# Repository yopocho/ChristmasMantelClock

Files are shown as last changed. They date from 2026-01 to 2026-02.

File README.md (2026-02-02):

<p align="left">
  <a href="https://github.com/zephyrproject-rtos/zephyr">
    
  </a>
  <a href="https://www.altium.com/altium-designer">
    
  </a>
  <a href="">
    
  </a>
</p>

# Christmas Mantel Clock

Hardware and firmware for a my 2025 christmas present to friends and family. This repository describes the device I designed, which is built around an STM32 microcontroller running Zephyr RTOS with LVGL/EEZ Studio UI.

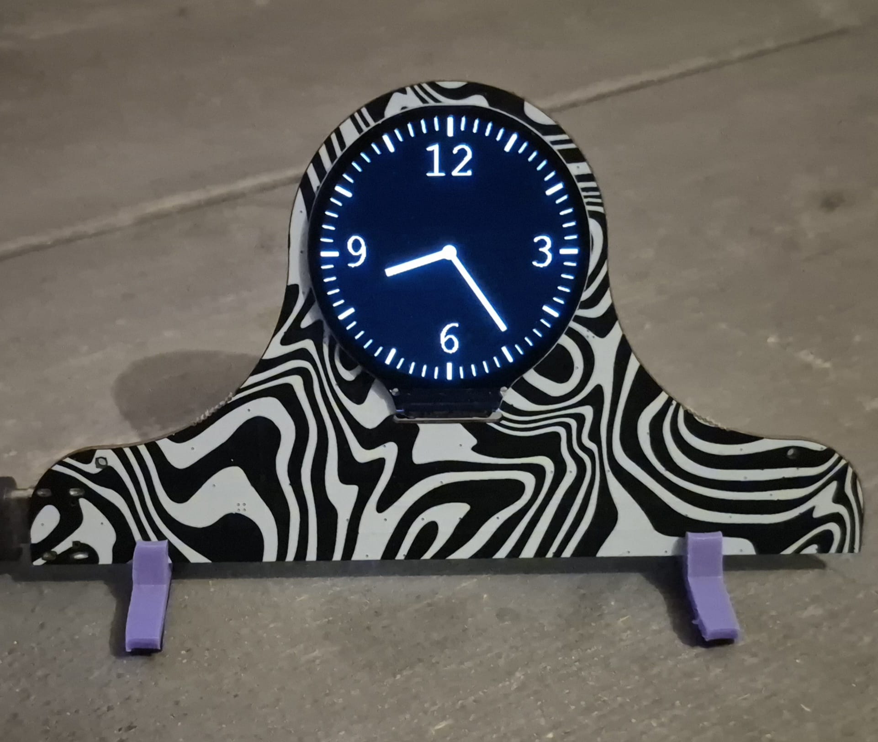
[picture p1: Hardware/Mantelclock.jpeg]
Image of the finished mantel clock


This repository is intended as a reference for the design, including electronics, firmware, and build configuration.

## Features

- Custom PCB and hardware design
- GC9A01 240x240 1.28" round LCD
- Zephyr RTOS board definition based on the PCB
- STM32F405-based firmware
- Zephyr RTOS configuration
- Windows-based build scripts

Designed as a standalone mantel clock, nice for on the mantel!

## Getting Started

### Prerequisites

- ARM GCC toolchain
- CMake 3.20 or newer
- Zephyr SDK and dependencies
- West Metatool
- Windows build environment (CMD or PowerShell)

### Build

From the repository root:

```bat
build.bat
```

To perform a clean (pristine) build:

```bat
build_pristine.bat
```

## Configuration

- `mantelclock_defconfig`
  Default configuration associated with the mantel clock board, enabling required drivers and functionality for bare-bones implementation
- `prj.conf`  
  Implementation-specific configuration

## Flashing and Debugging

1. Connect a supported debugger (ST-Link, J-Link, etc.). 
3. Flash the generated image to the target device (DFU or SWD).
4. Use a SWO-capable debugger for live SWO-trace logging and debugging

## Hardware

Hardware design files, including schematics and PCB layouts, are located under the `Hardware/` directory.
To replicate, simply use the supplied gerbers, -BOM and -CPL files and order the board (assembled) at JLCPCB.

Hardware designed using Altium Designer

## License

Apache License 2.0

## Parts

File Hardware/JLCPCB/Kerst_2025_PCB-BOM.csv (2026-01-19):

Comment | Description | Designator | Footprint | LibRef | Quantity | LCSC Part #
MY-2032-28 | Battery clip Nickel Phosphor Bronze CR2032 SMD Button And Strip Battery Connector ROHS | BT301 | MY-2032-28 | CMP-00029-00004-3 | 1
100n | Capacitor SMD 0402 | C201, C302, C304, C305, C306, C307, C308, C405 | CAP_0402 | CMP-001-00084-3 | 8 | C1525
2u2 | Capacitor SMD 0402 | C202, C203, C403, C404, C501, C502, C503 | CAP_0402 | CMP-001-00084-3 | 7 | C12530
1u | Capacitor SMD 0402 | C204, C205 | CAP_0402 | CMP-001-00084-3 | 2 | C52923
10u | Capacitor SMD 0603 | C301, C303, C504 | CAP_0603 | CMP-001-00085-2, CMP-001-00085-5 | 3 | C19702
14p 50V | Capacitor SMD 0402 | C401, C402 | CAP_0402 | CMP-001-00084-3 | 2 | C1548
15p 50V | Capacitor SMD 0402 | C406, C407 | CAP_0402 | CMP-001-00084-3 | 2 | C1548
USBLC6-2SC6 | Low-Capacitance ESD Protection USB | D201 | SOT-23-6 | CMP-004-00035-1 | 1 | C7519
LED_0603_RED | LED 0603 RED SMD | D401 | LED_0603_RED | CMP-004-00040-1 | 1 | C2286
D_BI_TVS_SOD_323 | Bidirectional TVS Diode SMD SOD-323 | D402, D403, D404 | SOD-323 | CMP-004-00068-3 | 3 | C20615802
MINISMDC020F-2 | PTC RESET FUSE 30V 200MA 1812 | F201 | FP-MINISMDC020F-2-MFG | CMP-08606-000054-1 | 1 | C5418
120R | Chip Ferrite Bead, 0603, 120O @ 100MHz, 0.05O, 25%, 2A BLM18PG121SN1D | FB201 | FP-BLM18-0_15-t0_8-IPC_A | CMP-0686-00557-7 | 1 | C14709
TYPE-C-31-M-12 | USB Type-C Connector JLCPCB C165948 | J201 | CONN12_C-31-M-12_HRO | CMP-002-00157-2 | 1 | C165948
HL2305 | P-CHANNEL 20-V (D-S) MOSFET SI2301CDS-T1-GE3 (PLACEHOLDER FOR ACTUAL PART HL2305 LCSC C28646261) | Q301 | TO-236_VIS | CMP-013-00034-4 | 1 | C28646261
AO3400A | MOSFET N-CH 30V 5.7A SOT23 | Q501 | FP-SOT23-MFG | CMP-83955-000006-1 | 1 | C20917
5k1 | Resistor SMD 0402 | R201, R202 | RES_0402 | CMP-009-00178-2 | 2 | C25905
0R | Resistor SMD 0402 | R401, R407, R504 | RES_0402 | CMP-009-00178-2 | 3 | C17168
10k | Resistor SMD 0402 | R402, R403, R404, R406, R408, R501, R503 | RES_0402 | CMP-009-00178-2 | 7 | C25744
1k | Resistor SMD 0402 | R405 | RES_0402 | CMP-009-00178-2 | 1 | C11702
51R | Resistor SMD 0805 | R502 | RES_0805 | CMP-009-00180-3 | 1 | C17738
TS-1088-AR02016 | Without Bracket 4mm 12V 3mm Round Button SPST 50mA SMD,4x3mm Tactile Switches RoHS | SW401, SW402, SW403 | SW_TS-1088_XNP | CMP-011-00038-2 | 3 | C720477
XC6206P332MR-G | 1uA 200mA 3.3V 6V Fixed Over Current Protection Positive SOT-23-3L Voltage Regulators - Linear, Low Drop Out (LDO) Regulators ROHS | U201 | SOT-23_TOR | CMP-019-00049-5 | 1 | C5446
STM32F405RGT6 | MCU 32-bit STM32F ARM Cortex M4F RISC 1024KB Flash 2.5V/3.3V 64-Pin LQFP Tray | U401 | STM-LQFP64_M | CMP-031-00038-1 | 1 | C15742
LDK220M30R | 200 mA low quiescent current and low noise LDO | U501 | SOT23-5L_1P75X3P05X0P95_STM | CMP-019-00050-3 | 1 | C5267990
25MHz 12pF | Crystal SMD 25MHz 10PPM 12pF 3225 X322525MOB4SI YXC JLCPCB C9006 | X401 | XTAL_3225 | CMP-003-00033-1 | 1 | C9006
32.768kHz 12.5pF | 32.768kHz Crystal Oscillator (JLCPCB C32346) | X402 | XTAL_FC-135_EPS | CMP-003-00034-4 | 1 | C32346

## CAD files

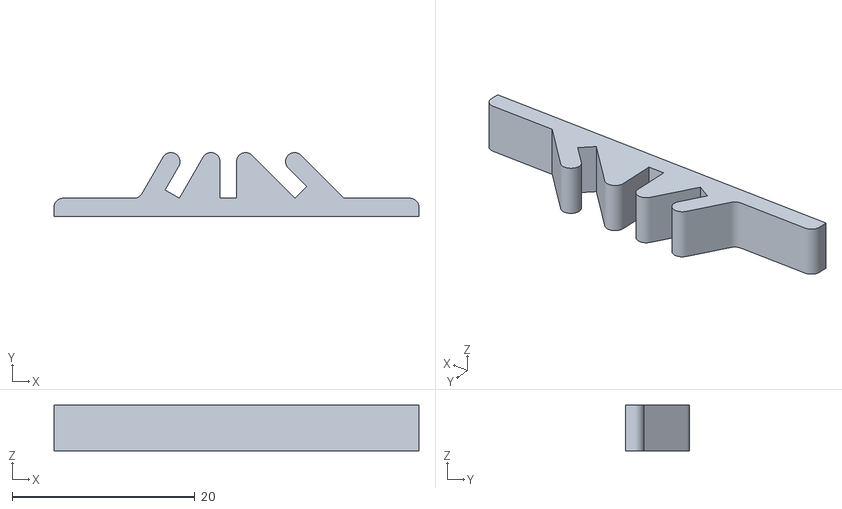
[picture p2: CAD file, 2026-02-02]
Hardware/Mantel_Clock_Stand.stl
40.0 x 7.00 x 5.00

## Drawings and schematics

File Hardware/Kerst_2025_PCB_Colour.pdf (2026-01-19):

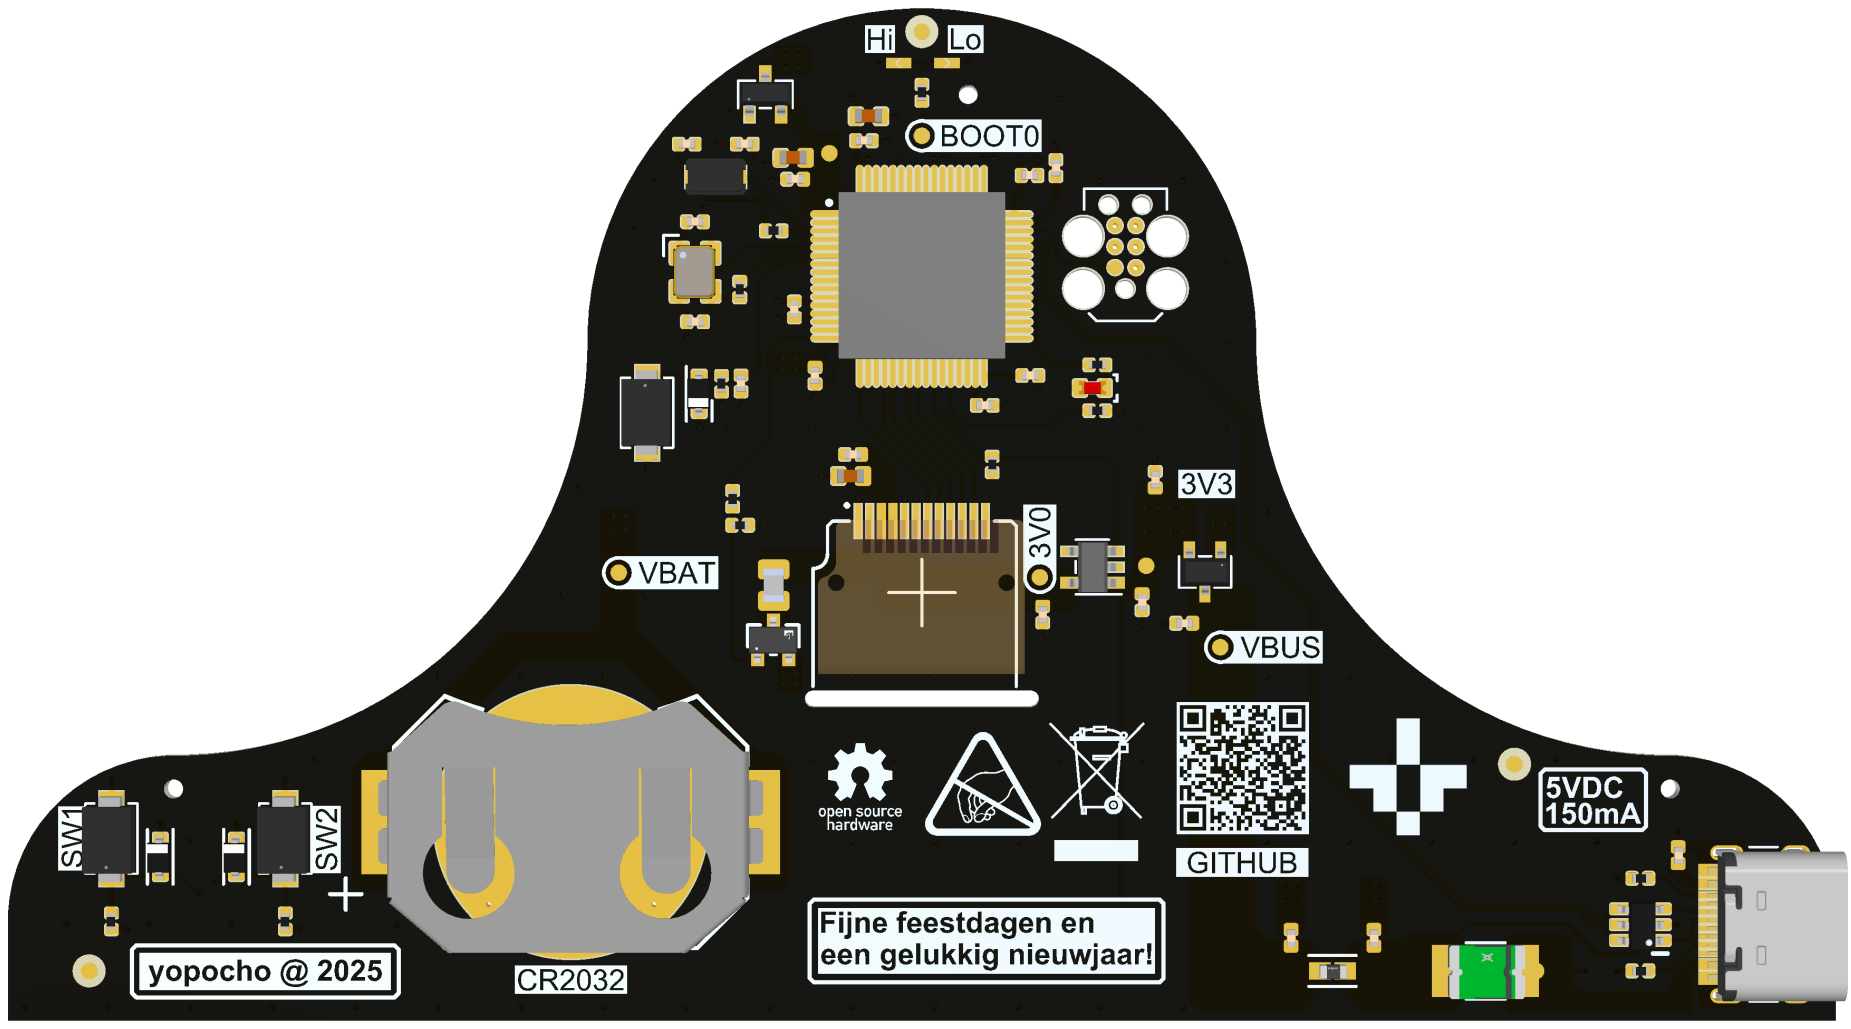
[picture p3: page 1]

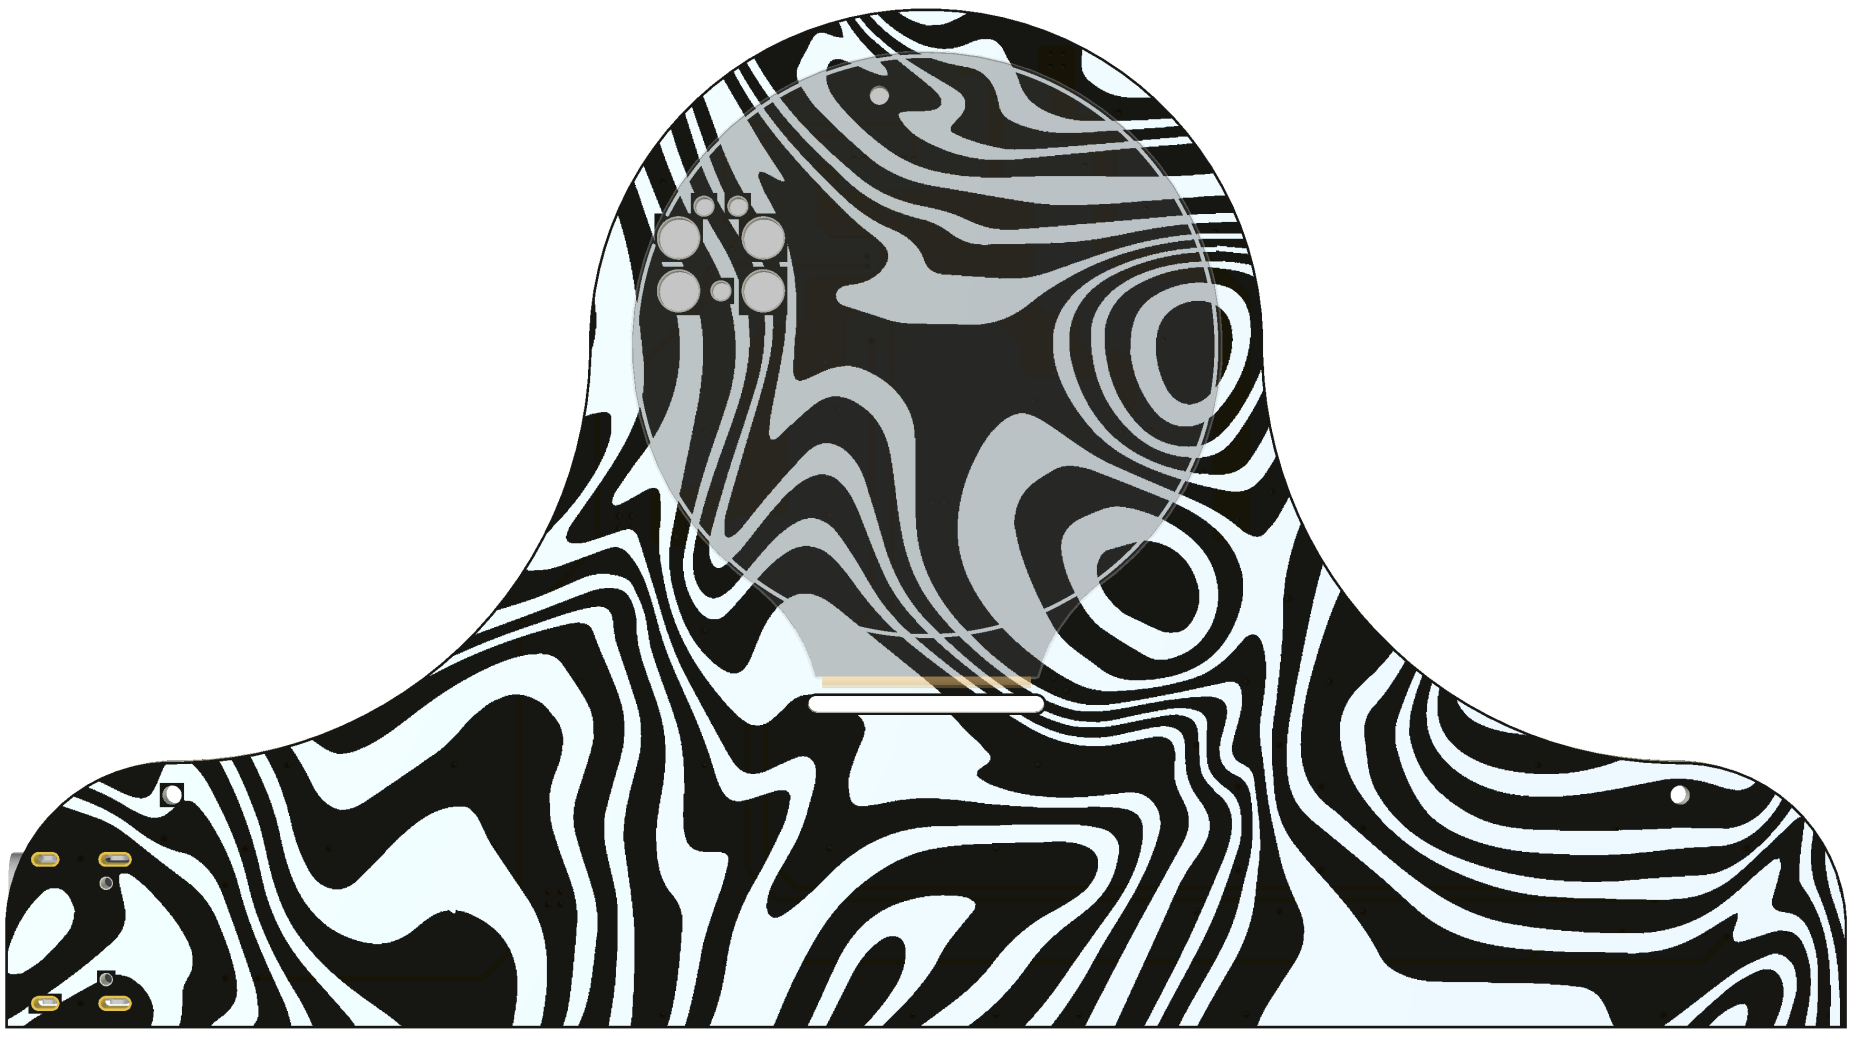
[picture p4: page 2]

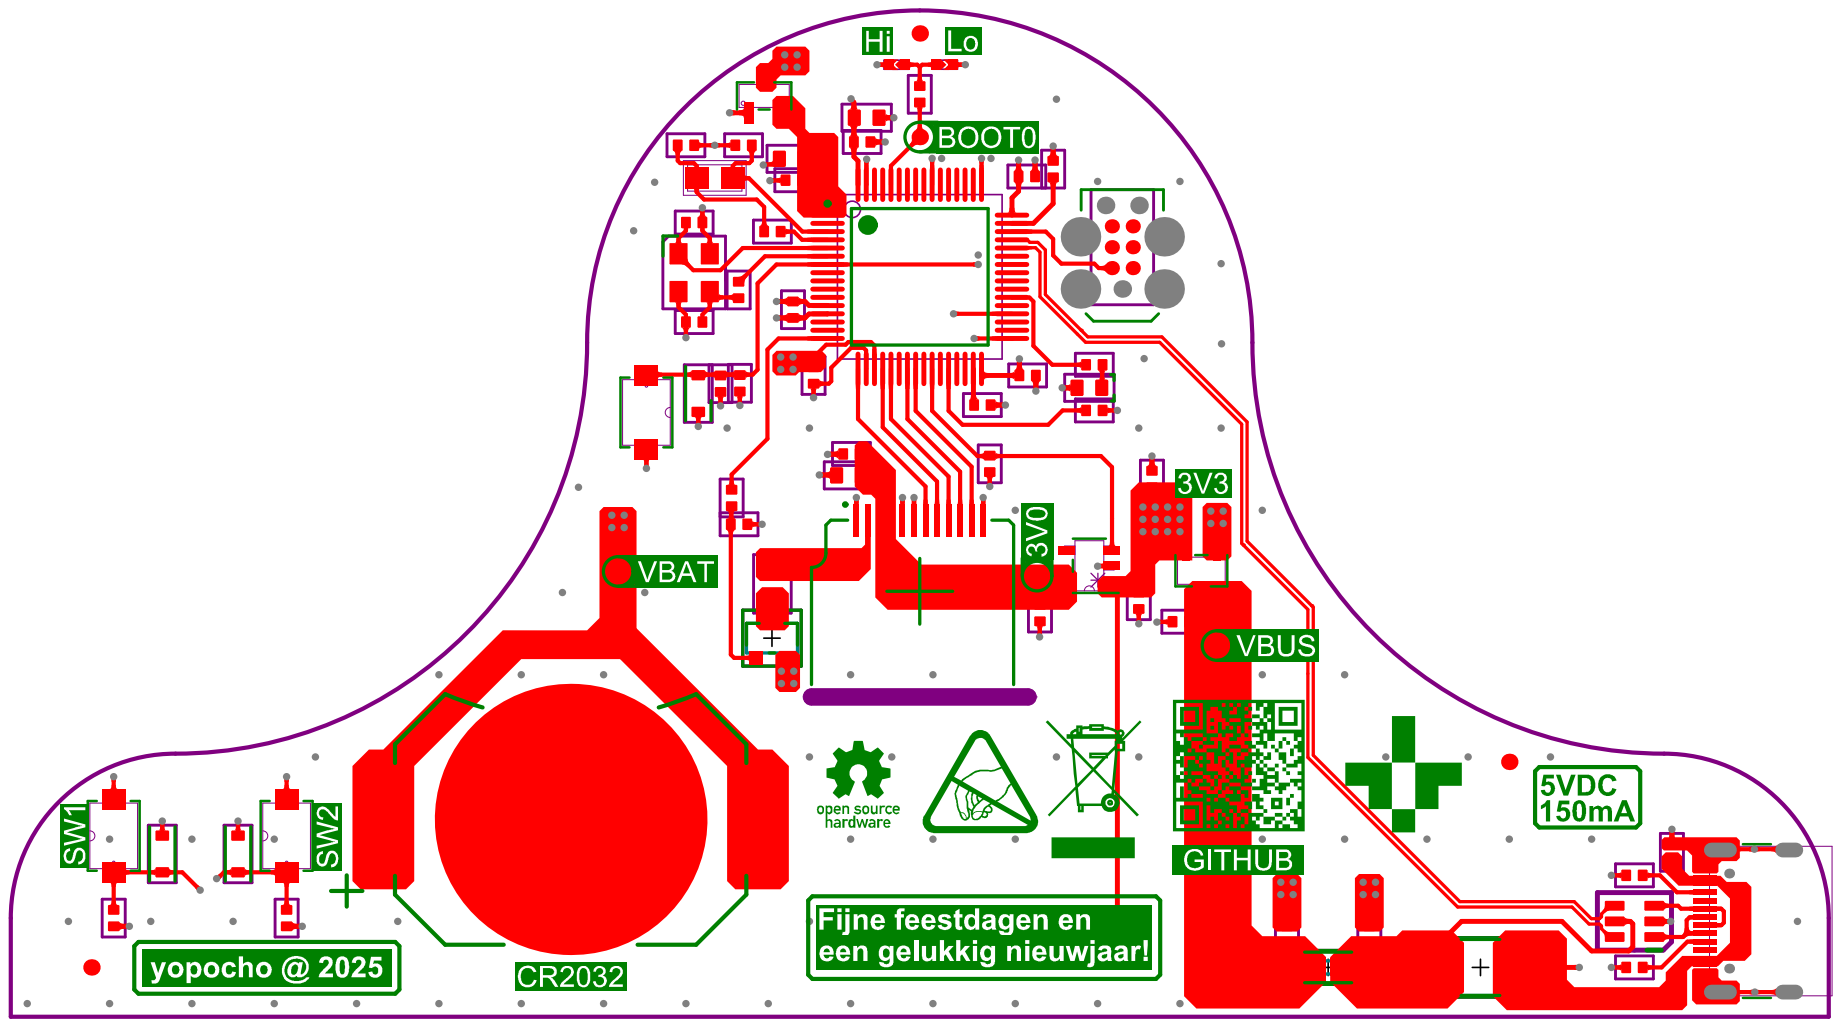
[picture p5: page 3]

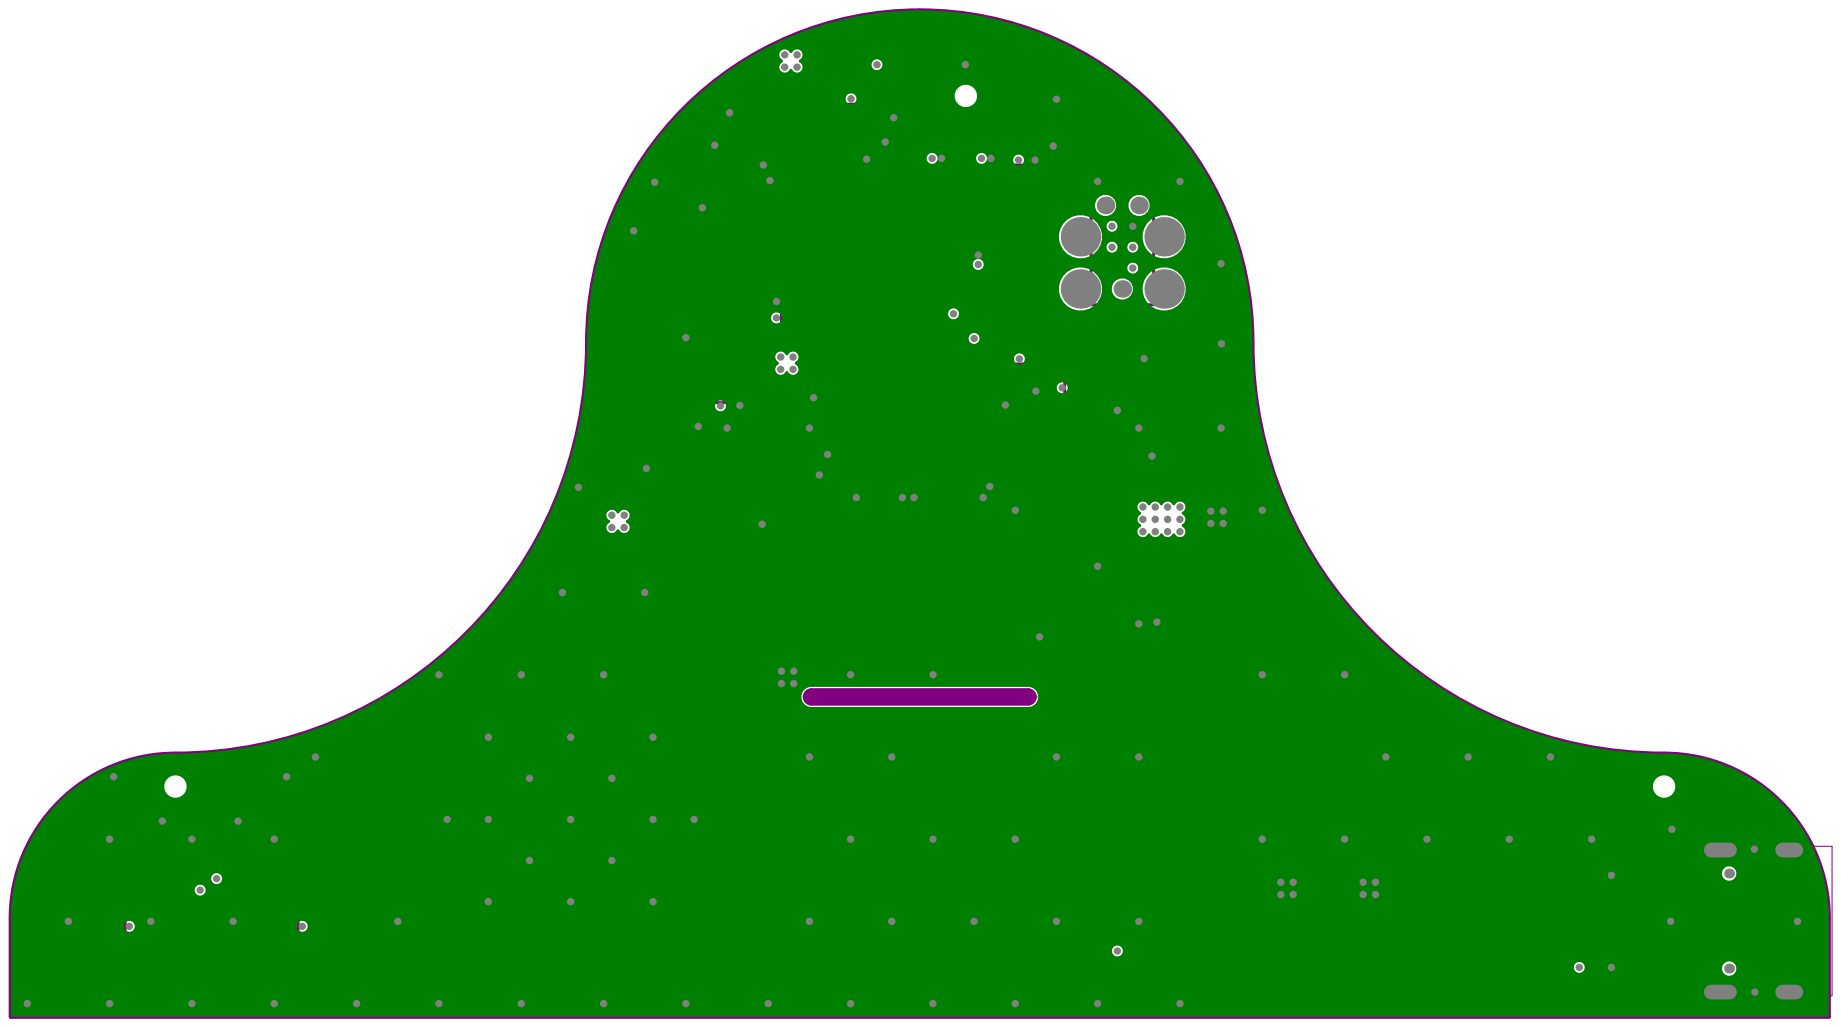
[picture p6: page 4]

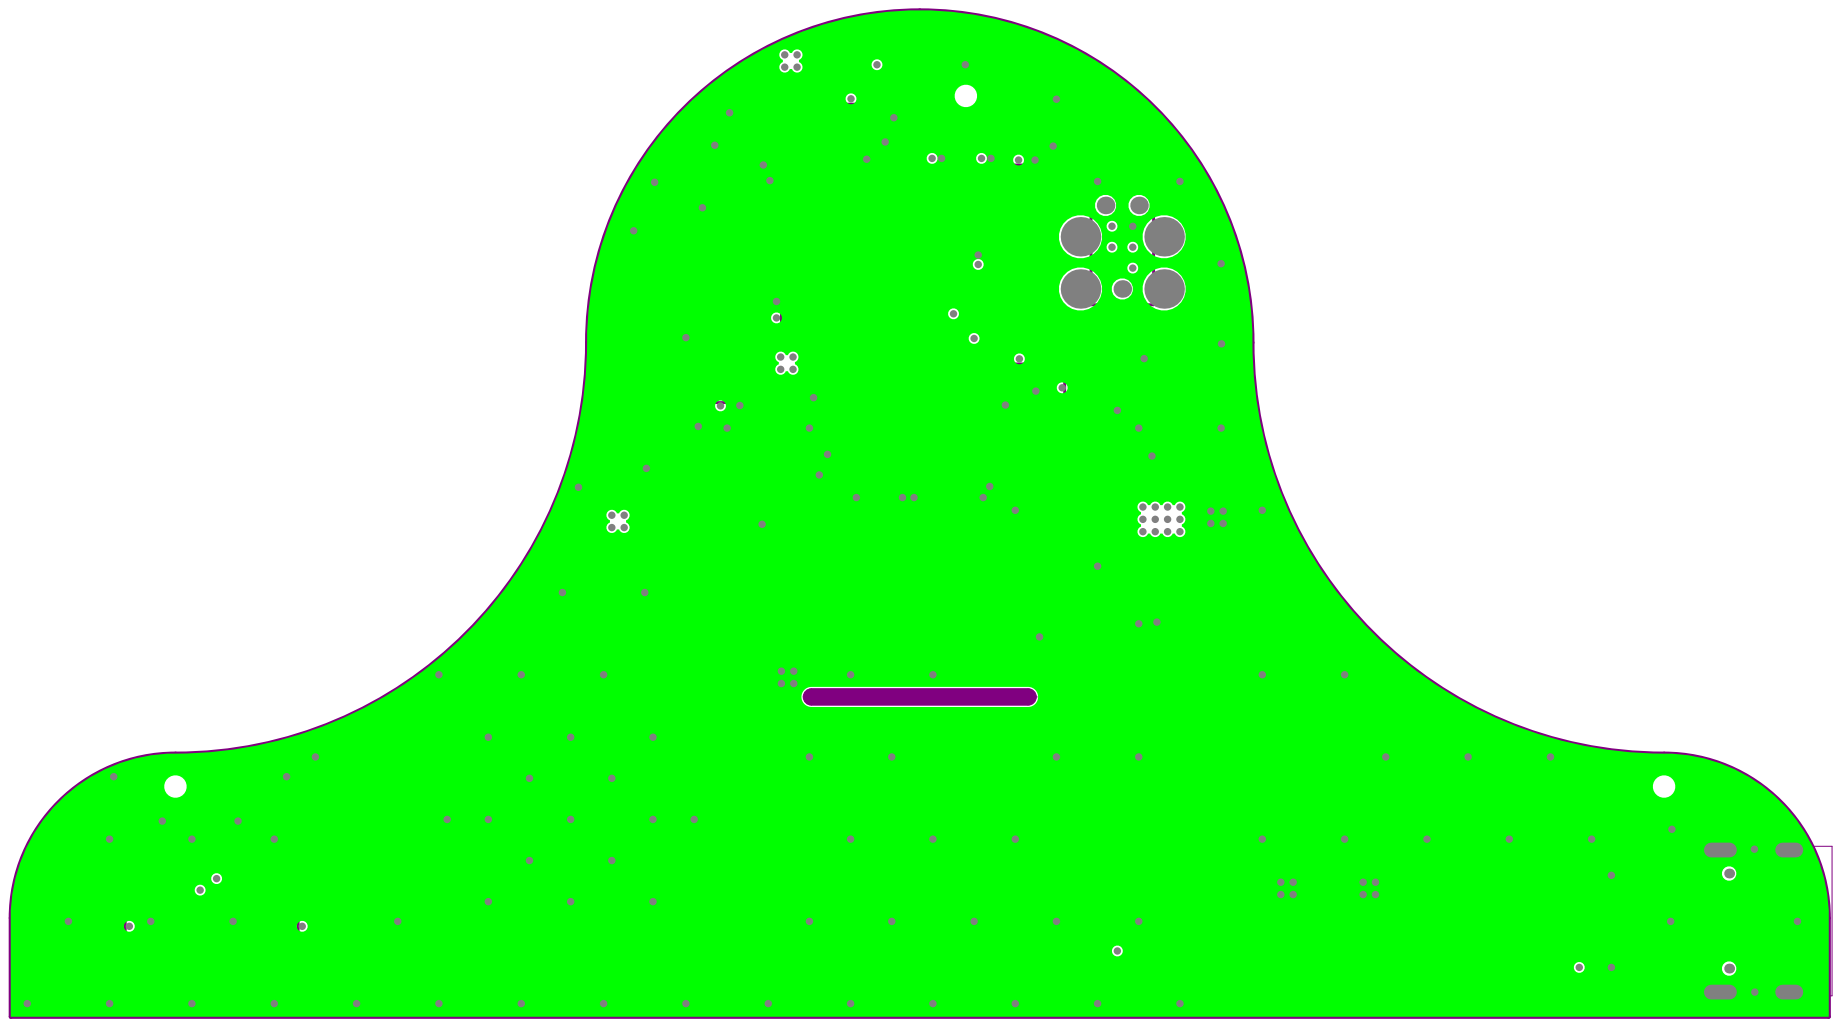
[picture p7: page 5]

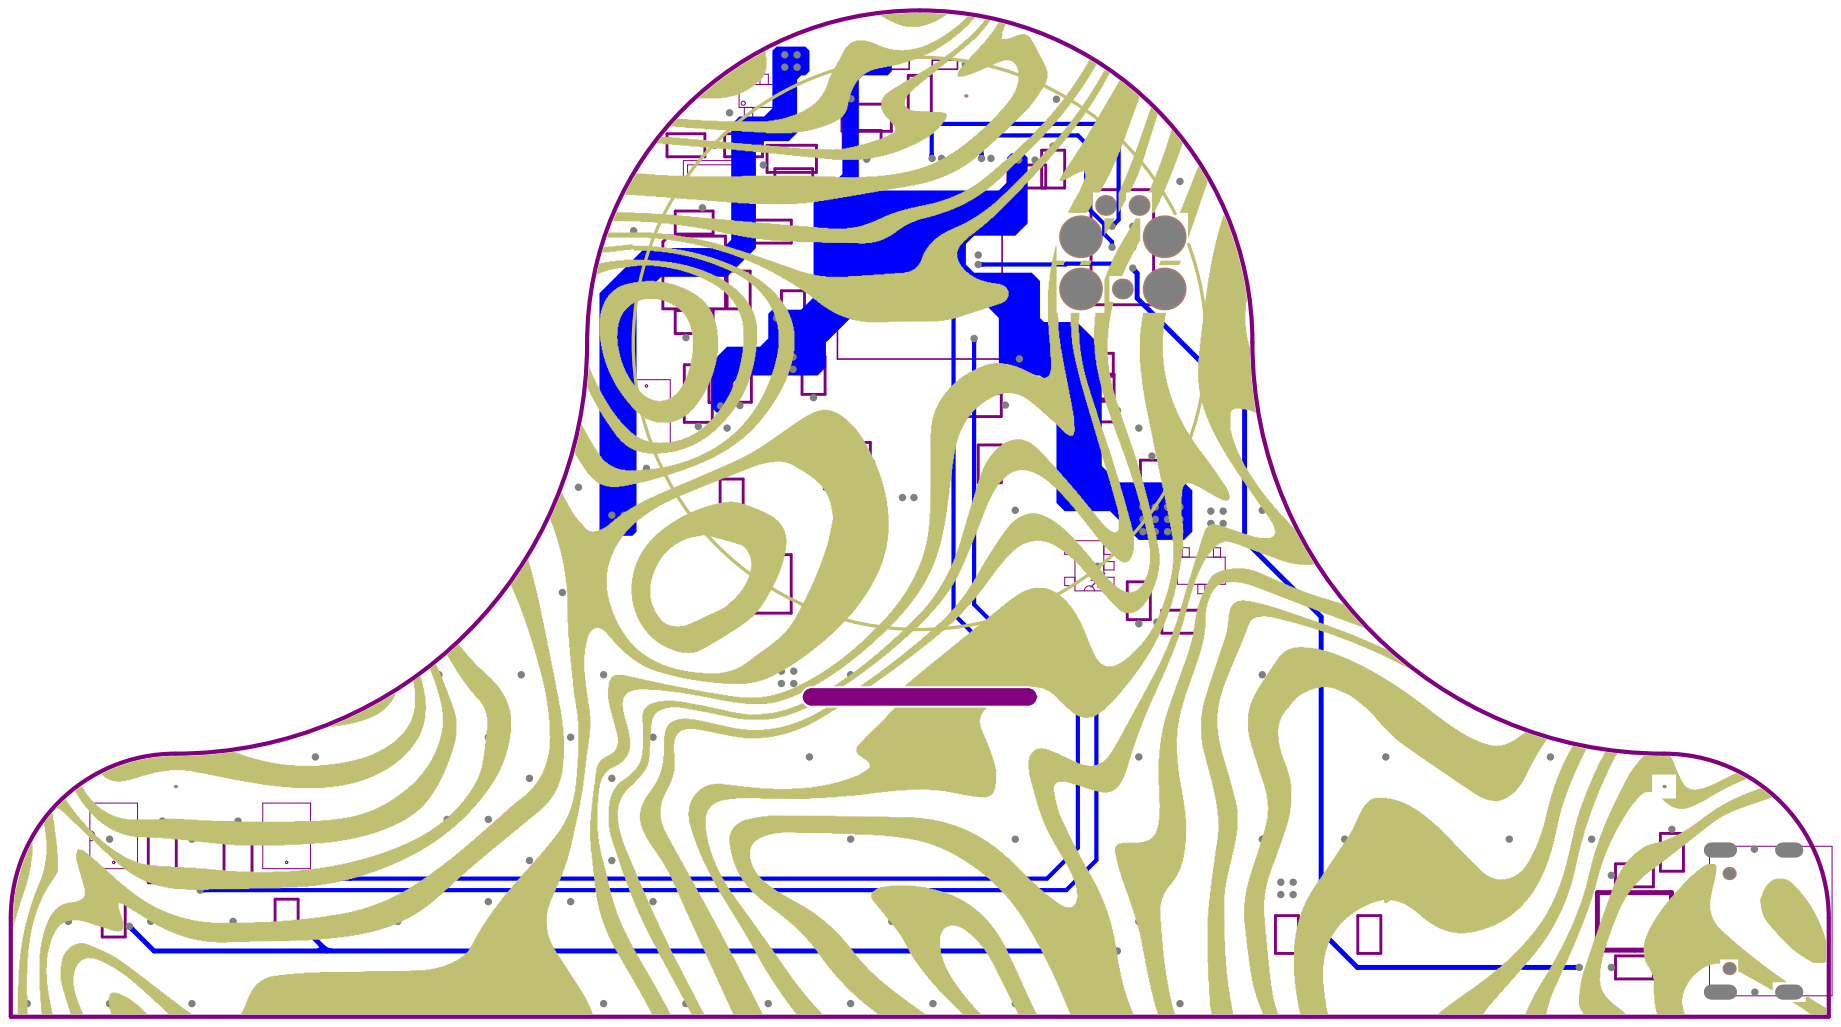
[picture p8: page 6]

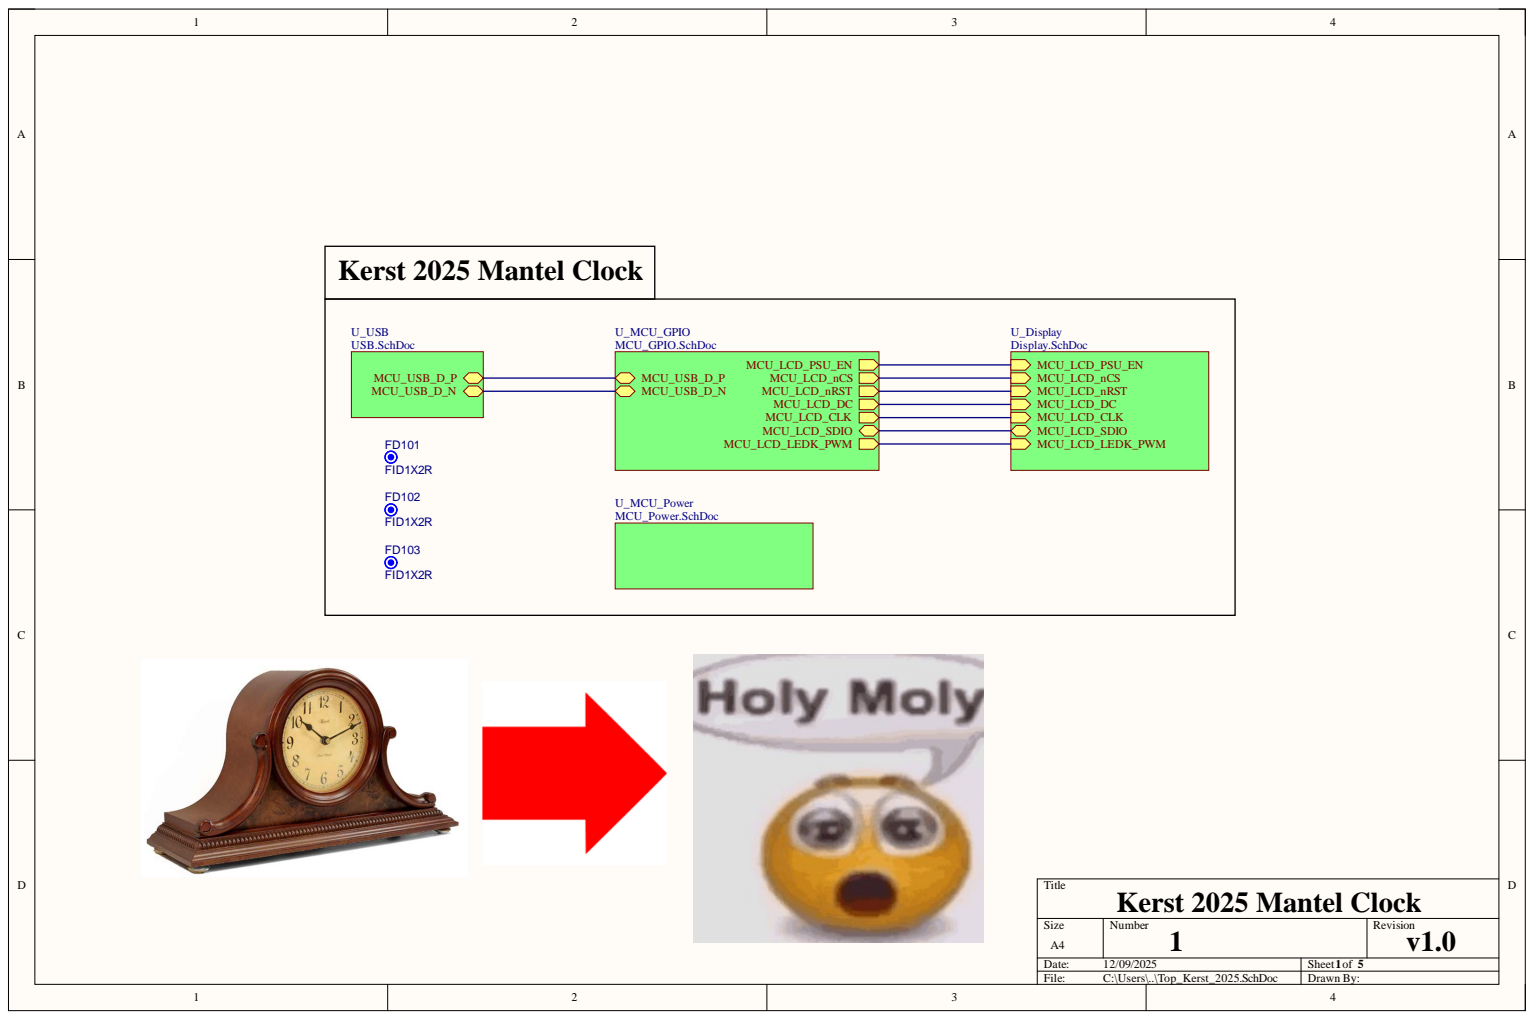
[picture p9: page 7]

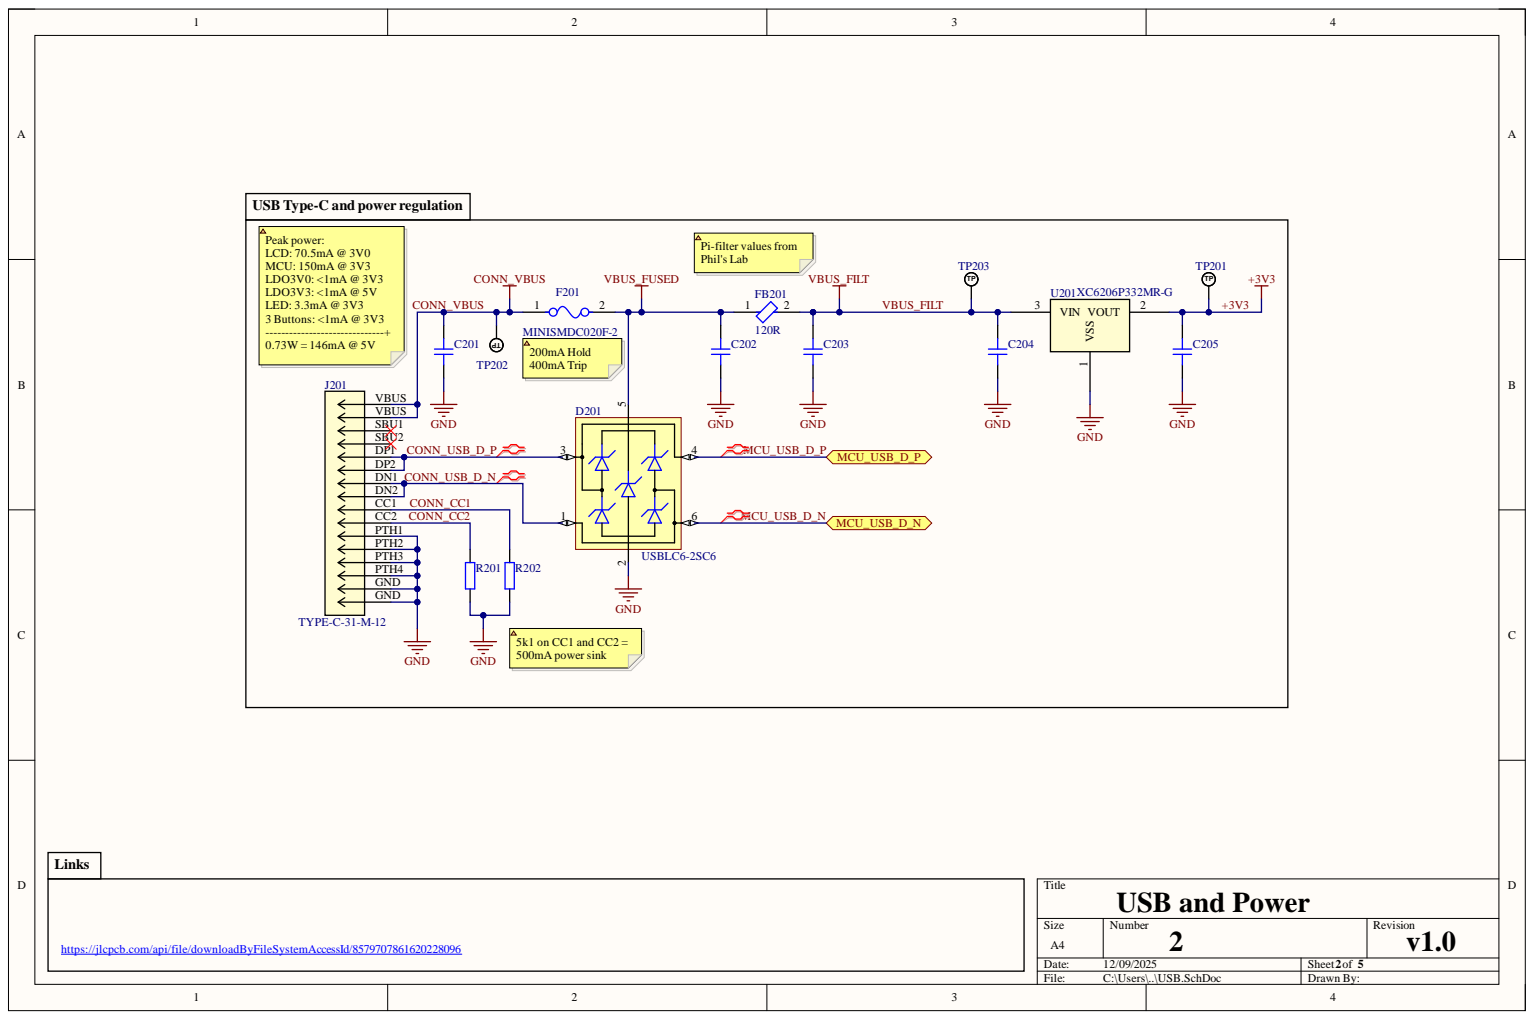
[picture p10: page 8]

USB Type-C and power regulation

Pi-filter values from
Phil's Lab

https://jlcpcb.com/api/file/downloadByFileSystemAccessId/8579707861620228096

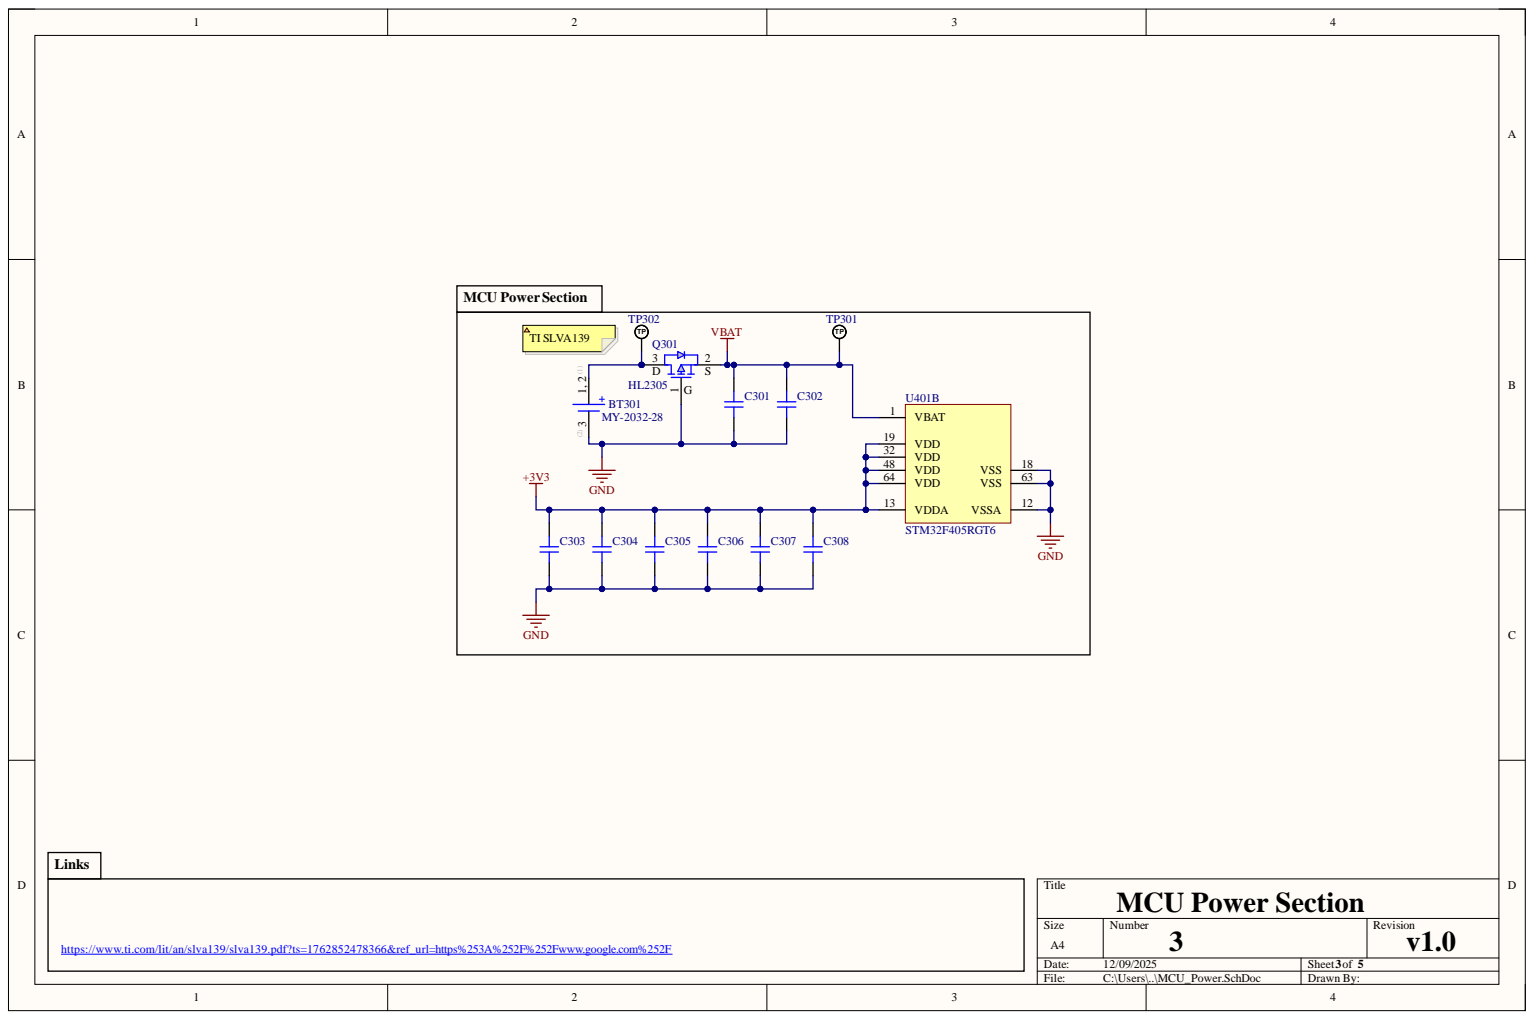
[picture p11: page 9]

https://www.ti.com/lit/an/slva139/slva139.pdf?ts=1762852478366&ref_url=https%253A%252F%252Fwww.google.com%252F

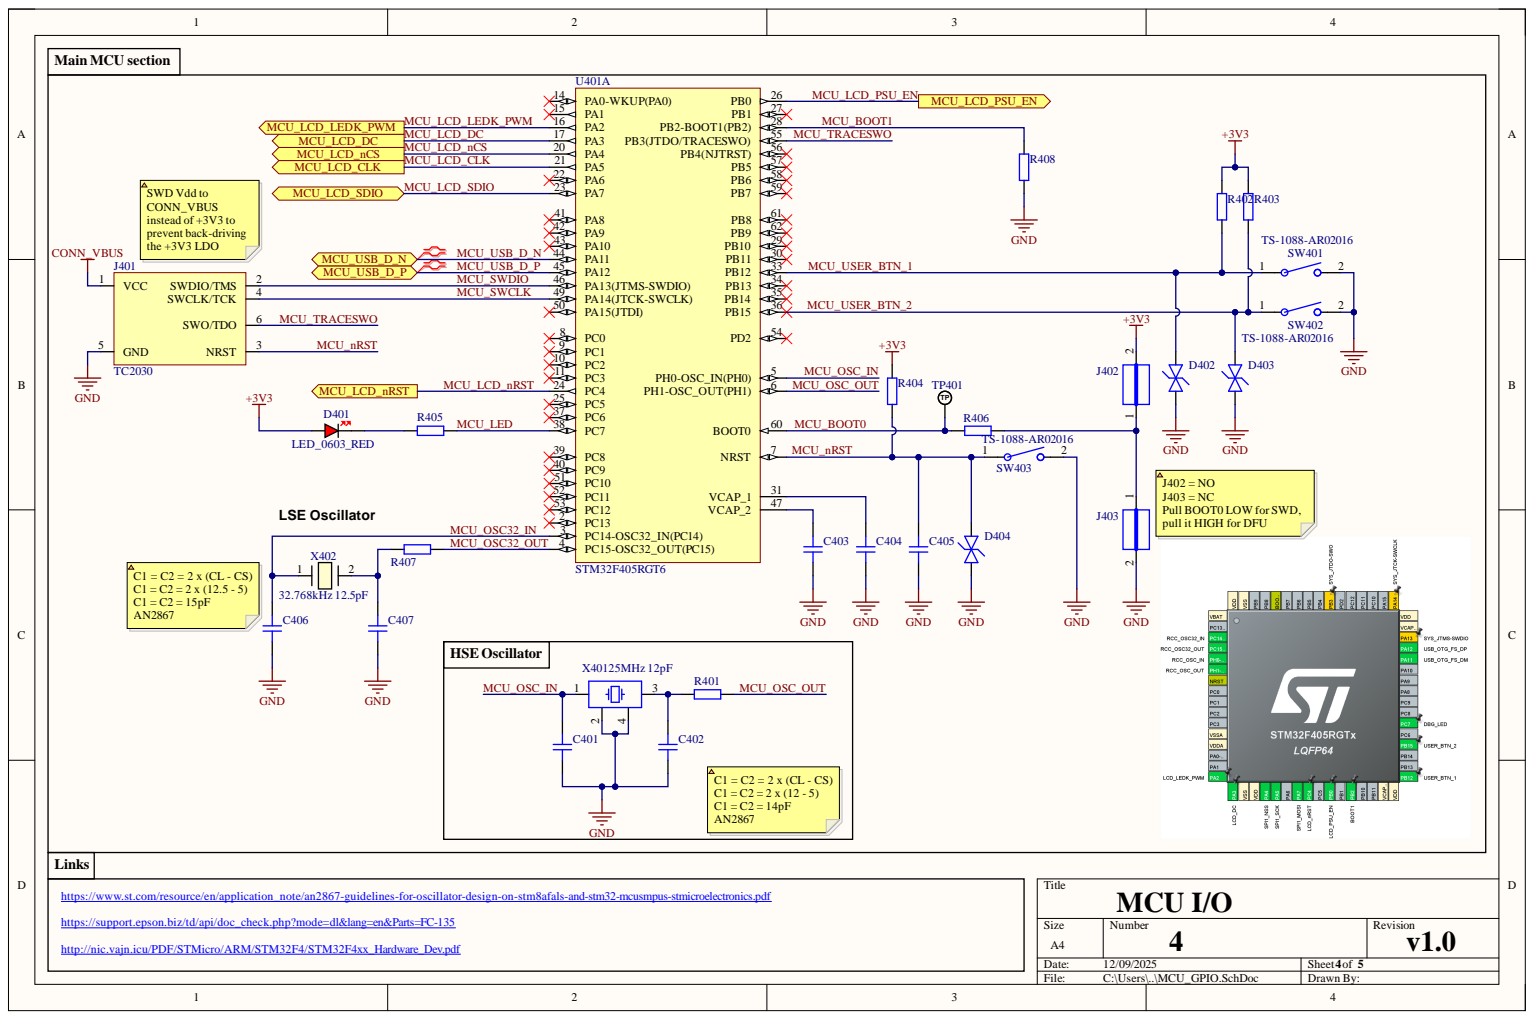
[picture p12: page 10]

Pull BOOT0 LOW for SWD,
pull it HIGH for DFU

https://www.st.com/resource/en/application_note/an2867-guidelines-for-oscillator-design-on-stm8afals-and-stm32-mcusmpus-stmicroelectronics.pdf

https://support.epson.biz/td/api/doc_check.php?mode=dl&lang=en&Parts=FC-135

http://nic.vajn.icu/PDF/STMicro/ARM/STM32F4/STM32F4xx_Hardware_Dev.pdf

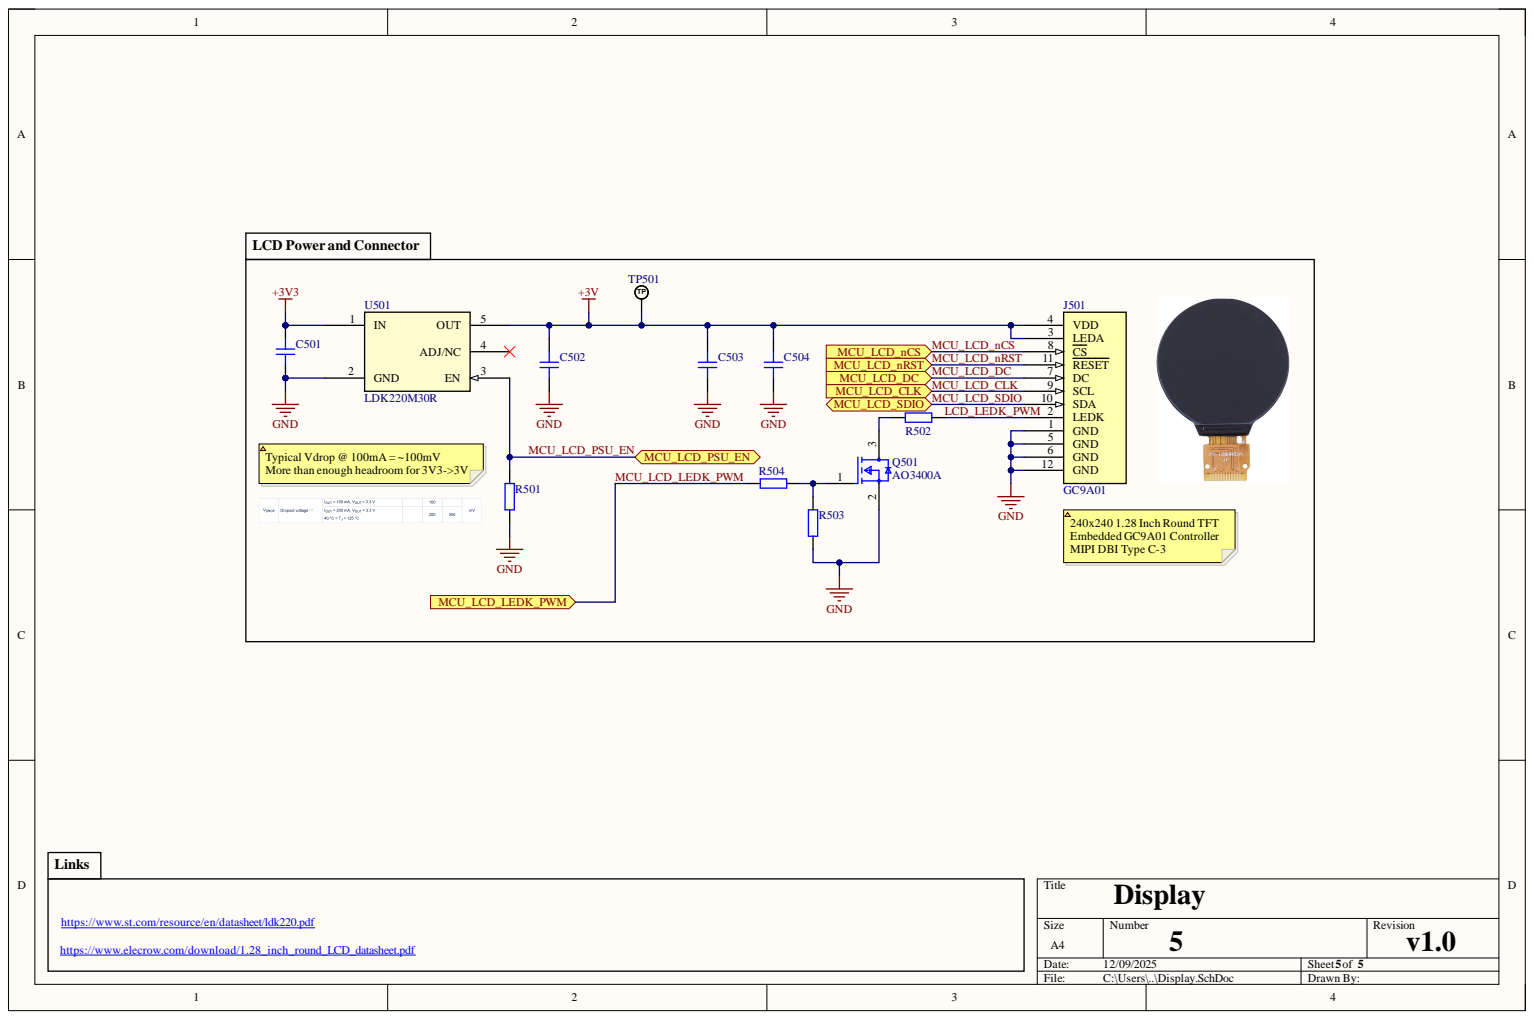
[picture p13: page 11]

LCD Power and Connector

Typical Vdrop @ 100mA = ~100mV
More than enough headroom for 3V3->3V

https://www.st.com/resource/en/datasheet/ldk220.pdf

https://www.elecrow.com/download/1.28_inch_round_LCD_datasheet.pdf

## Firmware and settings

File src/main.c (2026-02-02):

/* Zephyr */
#include <zephyr/kernel.h>
#include <zephyr/sys/util.h>
#include <zephyr/device.h>
#include <zephyr/logging/log.h>
#include <zephyr/sys/printk.h>
#include <zephyr/drivers/gpio.h>
#include <zephyr/drivers/display.h>
#include <zephyr/drivers/rtc.h>
#include <zephyr/drivers/pwm.h>
#include <zephyr/storage/flash_map.h>
#include <zephyr/sys/crc.h>
/* LVGL */
#include <lvgl.h>
/* UI */
#include "ui/ui.h"
#include "ui/styles.h"
/* Local */
#include "settings.h"
/* C */
#include <string.h>
#include <stdio.h>
#include <stdint.h>
 
/* Defines */
#define LOG_LEVEL LOG_LEVEL_DBG
#define FRAME_TIME_TARGET 10 // ms. ~100 FPS for a clock is plenty lol
#define PWM_PERIOD PWM_USEC(10) // us
#define SETTINGS_MAGIC 0xFEEDBEEF // Search data for flash journal

/* Prototypes */
static int set_date_time(const struct device *rtc, struct rtc_time *settable_time);
static int get_date_time(const struct device *rtc, struct rtc_time *target_time);
static void display_time(void);
static int setup_dt(void);
static int setup_lvgl(void);
static void update_background_colour(colours_t colour);
static void update_text_colour(colours_t colour);

/* Prototypes for EEZ Studio callbacks on LVGL events */
void action_change_screen(lv_event_t * e);
void action_digital_clock_set_time_save(lv_event_t * e);
void action_menu_save(lv_event_t * e);
void action_menu_clock_type_value_changed(lv_event_t * e);
void action_menu_background_colour_value_changed(lv_event_t * e);
void action_menu_text_colour_value_changed(lv_event_t * e);
void action_menu_brightness_value_changed(lv_event_t * e);
void action_flush_finished(lv_event_t *e);

/* Get devices from devicetree */
static const struct gpio_dt_spec dbg_led = GPIO_DT_SPEC_GET(DT_ALIAS(led0), gpios);
static const struct pwm_dt_spec  LCD_kathode_pwm = PWM_DT_SPEC_GET(DT_ALIAS(kathodepwm));
static const struct device *GC9A01 = DEVICE_DT_GET(DT_CHOSEN(zephyr_display));
static const struct device *const rtc = DEVICE_DT_GET(DT_ALIAS(rtc));
static const struct device *indev_dt = DEVICE_DT_GET(DT_COMPAT_GET_ANY_STATUS_OKAY(zephyr_lvgl_keypad_input));

/* RTC Calender */
static struct rtc_time tm = {
	.tm_year = 2026 - 1900,
	.tm_mon = 01 - 1,
	.tm_mday = 12,
	.tm_hour = 23,
	.tm_min = 10,
	.tm_sec = 24,
};

/* Default user settings*/
user_settings_t user_settings = {
	.brightness = 100,
	.clock_type = CLOCK_TYPE_DIGITAL,
	.background_colour = Black,
	.text_colour = White
};

/* Flags */
bool setup_done = false;
bool first_flush_complete = false;
uint8_t flush_cb_cntr = 0;

/* LVGL */
lv_indev_t * indev;

/* PWM */
uint8_t brightness;

/* Logging */
LOG_MODULE_REGISTER(logging_mantelclock, LOG_LEVEL_DBG);

/* Required global variables for EEZ UI */
char time_hr_global[100] = { 0 };
char time_min_global[100] = { 0 };

/* Style definitions */
lv_color_t temp_selection_background_colour;
lv_color_t temp_selection_text_colour;
lv_style_t * temp_style_spinboxes_menu;
lv_style_t * temp_style_spinboxes_menu_FOCUSKEY;
lv_style_t * temp_style_spinboxes_menu_CURSOR;
lv_style_t * temp_style_spinboxes_digital_clock;
lv_style_t * temp_style_spinboxes_digital_clock_FOCUSKEY;
lv_style_t * temp_style_spinboxes_digital_clock_CURSOR;
lv_style_t * temp_style_scale_analog_clock;
lv_style_t * temp_style_scale_analog_clock_INDICATOR;
lv_style_t * temp_style_scale_analog_clock_ITEMS;
lv_style_t * temp_style_rollers_menu;
lv_style_t * temp_style_rollers_menu_FOCUSKEY;
lv_style_t * temp_style_rollers_menu_SELECTED;
lv_style_t * temp_style_line_hr_analog_clock;
lv_style_t * temp_style_line_min_analog_clock;
lv_style_t * temp_style_labels_menu;
lv_style_t * temp_style_labels_digital_clock;
lv_style_t * temp_style_labels_analog_clock;
lv_style_t * temp_style_buttons_menu;
lv_style_t * temp_style_buttons_menu_FOCUSKEY;
lv_style_t * temp_style_buttons_digital_clock_set_time;
lv_style_t * temp_style_buttons_digital_clock_set_time_FOCUSKEY;

/* Set initial screen as SCREEN_DIGITAL_CLOCK (TODO: For now, this has to be retrieved from user settings eventually) */
screens current_screen = SCREEN_NONE;
screens next_screen = SCREEN_NONE;
screens previous_screen = SCREEN_NONE;

struct rtc_time current_time;

/* Flash */
static const struct flash_area *fa;
static size_t write_offset;

/* Flash settings */
struct __packed settings_record {
	uint32_t magic;
	uint16_t version;
	uint16_t length;
	uint32_t crc;
	struct user_settings_t settings;
};

/**
 * @brief Helper function for converting between local colour enum index and LVGL lv_color_t
 * 
 * @param colour colours_t colour index
 * 
 * @retval lv_color_t from colour colours_t index
 */
lv_color_t get_color_from_index(colours_t colour) {
	switch(colour) {
		case White:
			return lv_color_white();
			break;
		case Black:
			return lv_color_black();
			break;
		case Red:
			return lv_palette_main(LV_PALETTE_RED);
			break;
		case Pink:
			return lv_color_lighten(lv_palette_main(LV_PALETTE_PINK), 100);
			break;
		case Purple:
			return lv_palette_main(LV_PALETTE_PURPLE);
			break;
		case Indigo:
			return lv_palette_main(LV_PALETTE_INDIGO);
			break;
		case Blue:
			return lv_palette_main(LV_PALETTE_BLUE);
			break;
		case Cyan:
			return lv_palette_main(LV_PALETTE_CYAN);
			break;
		case Teal:
			return lv_palette_main(LV_PALETTE_TEAL);
			break;
		case Green:
			return lv_palette_main(LV_PALETTE_GREEN);
			break;
		case Lime:
			return lv_palette_main(LV_PALETTE_LIME);
			break;
		case Yellow:
			return lv_palette_main(LV_PALETTE_YELLOW);
			break;
		case Amber:
			return lv_palette_main(LV_PALETTE_AMBER);
			break;
		case Orange:
			return lv_palette_main(LV_PALETTE_ORANGE);
			break;
		case Brown:
			return lv_palette_main(LV_PALETTE_BROWN);
			break;
		case Gray:
			return lv_palette_main(LV_PALETTE_GREY);
			break;	
		default:
			return lv_color_white();
			break;
		};
	return lv_color_white();
}

/**
 * @brief Utility function for switching screens
 */
void check_screen_switching(void) {
	/* Switch screens manually, updated through EEZ UI action callback */
	if(next_screen != current_screen) {
		switch(next_screen) {
			case SCREEN_DIGITAL_CLOCK:
				LOG_DBG("Switching to SCREEN_DIGITAL_CLOCK");
				lv_indev_set_group(indev, groups.group_digital_clock);
				lv_obj_remove_flag(objects.cont_digital_clock, LV_OBJ_FLAG_HIDDEN);
				lv_obj_add_flag(objects.cont_digital_clock_set_time, LV_OBJ_FLAG_HIDDEN);
				lv_obj_add_flag(objects.cont_buttons_digital_clock_set_time, LV_OBJ_FLAG_HIDDEN);
				lv_obj_add_flag(objects.cont_analog_clock, LV_OBJ_FLAG_HIDDEN);
				lv_group_focus_obj(objects.label_time_hr_digital_clock);
				display_time();
				if(lv_screen_active() != objects.scr_digital_clock) loadScreen(SCREEN_ID_SCR_DIGITAL_CLOCK);
				previous_screen = current_screen;
				current_screen = SCREEN_DIGITAL_CLOCK;
				break;
			case SCREEN_ANALOG_CLOCK:
				LOG_DBG("Switching to SCREEN_ANALOG_CLOCK");
				lv_indev_set_group(indev, groups.group_analog_clock);
				lv_obj_add_flag(objects.cont_digital_clock, LV_OBJ_FLAG_HIDDEN);
				lv_obj_add_flag(objects.cont_digital_clock_set_time, LV_OBJ_FLAG_HIDDEN);
				lv_obj_add_flag(objects.cont_buttons_digital_clock_set_time, LV_OBJ_FLAG_HIDDEN);
				lv_obj_remove_flag(objects.cont_analog_clock, LV_OBJ_FLAG_HIDDEN);
				lv_group_focus_obj(objects.scale_analog_clock);
				display_time();
				if(lv_screen_active() != objects.scr_digital_clock) loadScreen(SCREEN_ID_SCR_DIGITAL_CLOCK);
				previous_screen = current_screen;
				current_screen = SCREEN_ANALOG_CLOCK;
				break;
			case SCREEN_DIGITAL_CLOCK_SET_TIME:
				LOG_DBG("Switching to SCREEN_DIGITAL_CLOCK_SET_TIME");
				if(lv_screen_active() != objects.scr_digital_clock) loadScreen(SCREEN_ID_SCR_DIGITAL_CLOCK);
				lv_indev_set_group(indev, groups.group_digital_clock_set_time);
				lv_obj_add_flag(objects.cont_digital_clock, LV_OBJ_FLAG_HIDDEN);
				lv_obj_add_flag(objects.cont_analog_clock, LV_OBJ_FLAG_HIDDEN);
				lv_obj_remove_flag(objects.cont_digital_clock_set_time, LV_OBJ_FLAG_HIDDEN);
				lv_obj_remove_flag(objects.cont_buttons_digital_clock_set_time, LV_OBJ_FLAG_HIDDEN);
				lv_spinbox_set_value(objects.spinbox_hr_digital_clock_set_time, current_time.tm_hour);
				lv_spinbox_set_value(objects.spinbox_min_digital_clock_set_time, current_time.tm_min);
				lv_group_focus_obj(objects.spinbox_hr_digital_clock_set_time);
				previous_screen = current_screen;
				current_screen = SCREEN_DIGITAL_CLOCK_SET_TIME;
				break;
			case SCREEN_ANALOG_CLOCK_SET_TIME:
				LOG_DBG("Switching to SCREEN_ANALOG_CLOCK_SET_TIME");
				// if(lv_screen_active() != objects.scr_analog_clock) loadScreen(SCREEN_ID_SCR_ANALOG_CLOCK);
				previous_screen = current_screen;
				current_screen = SCREEN_ANALOG_CLOCK_SET_TIME;
				break;
			case SCREEN_MENU:
				LOG_DBG("Switching to SCREEN_MENU");
				if(lv_screen_active() != objects.scr_menu) loadScreen(SCREEN_ID_SCR_MENU);
				temp_style_spinboxes_menu = get_style_style_spinboxes_menu_MAIN_DEFAULT();
				temp_style_spinboxes_menu_FOCUSKEY = get_style_style_spinboxes_menu_MAIN_FOCUS_KEY();
				temp_style_spinboxes_menu_CURSOR = get_style_style_spinboxes_menu_CURSOR_DEFAULT();
				temp_style_spinboxes_digital_clock = get_style_style_spinboxes_digital_clock_MAIN_DEFAULT();
				temp_style_spinboxes_digital_clock_FOCUSKEY = get_style_style_spinboxes_digital_clock_MAIN_FOCUS_KEY();
				temp_style_spinboxes_digital_clock_CURSOR = get_style_style_spinboxes_digital_clock_CURSOR_DEFAULT();
				temp_style_scale_analog_clock = get_style_style_scale_analog_clock_MAIN_DEFAULT();
				temp_style_scale_analog_clock_INDICATOR = get_style_style_scale_analog_clock_INDICATOR_DEFAULT();
				temp_style_scale_analog_clock_ITEMS = get_style_style_scale_analog_clock_ITEMS_DEFAULT();
				temp_style_rollers_menu = get_style_style_rollers_menu_MAIN_DEFAULT();
				temp_style_rollers_menu_FOCUSKEY = get_style_style_rollers_menu_MAIN_FOCUS_KEY();
				temp_style_rollers_menu_SELECTED = get_style_style_rollers_menu_SELECTED_DEFAULT();
				temp_style_labels_menu = get_style_style_labels_menu_MAIN_DEFAULT();
				temp_style_labels_digital_clock = get_style_style_labels_digital_clock_MAIN_DEFAULT();
				temp_style_labels_analog_clock = get_style_style_labels_analog_clock_MAIN_DEFAULT();
				temp_style_buttons_menu = get_style_style_buttons_menu_MAIN_DEFAULT();
				temp_style_buttons_menu_FOCUSKEY = get_style_style_buttons_menu_MAIN_FOCUS_KEY();
				temp_style_buttons_digital_clock_set_time = get_style_style_buttons_digital_clock_set_time_MAIN_DEFAULT();
				temp_style_buttons_digital_clock_set_time_FOCUSKEY = get_style_style_buttons_digital_clock_set_time_MAIN_FOCUS_KEY();
				temp_style_line_hr_analog_clock = get_style_style_line_hr_analog_clock_MAIN_DEFAULT();
				temp_style_line_min_analog_clock = get_style_style_line_min_analog_clock_MAIN_DEFAULT();
				lv_indev_set_group(indev, groups.group_menu);
				lv_group_focus_obj(objects.spinbox_menu_brightness);
				lv_obj_remove_event_cb(objects.spinbox_menu_brightness, action_menu_brightness_value_changed);
				lv_obj_remove_event_cb(objects.roller_menu_background_colour, action_menu_background_colour_value_changed);
				lv_obj_remove_event_cb(objects.roller_menu_text_colour, action_menu_text_colour_value_changed);
				lv_obj_remove_event_cb(objects.roller_menu_clock_type, action_menu_clock_type_value_changed);
				lv_spinbox_set_value(objects.spinbox_menu_brightness, user_settings.brightness);
				lv_roller_set_selected(objects.roller_menu_background_colour, user_settings.background_colour, LV_ANIM_OFF);
				lv_roller_set_selected(objects.roller_menu_text_colour, user_settings.text_colour, LV_ANIM_OFF);
				lv_roller_set_selected(objects.roller_menu_clock_type, user_settings.clock_type, LV_ANIM_OFF);
				lv_obj_add_event_cb(objects.spinbox_menu_brightness, action_menu_brightness_value_changed, LV_EVENT_VALUE_CHANGED, (void *)0);
				lv_obj_add_event_cb(objects.roller_menu_background_colour, action_menu_background_colour_value_changed, LV_EVENT_KEY, (void *)0);
				lv_obj_add_event_cb(objects.roller_menu_text_colour, action_menu_text_colour_value_changed, LV_EVENT_KEY, (void *)0);
				lv_obj_add_event_cb(objects.roller_menu_clock_type, action_menu_clock_type_value_changed, LV_EVENT_KEY, (void *)0);
				previous_screen = current_screen;
				current_screen = SCREEN_MENU;
				break;
			default:
				// Do nothing
				break;
		}
	}
}

/**
 * @brief Utility function for changing the display background colour 
 * 
 * @param colour colours_t colour index
 */
void update_background_colour(colours_t colour) {
	lv_color_t current_bg_colour = lv_obj_get_style_bg_color(objects.scr_digital_clock, LV_PART_MAIN);
	lv_color_t target_colour = get_color_from_index(colour);
	if(lv_color_to_u32(target_colour) != lv_color_to_u32(current_bg_colour)) {
		LOG_DBG("Setting new background colour");
		lv_obj_set_style_bg_color(objects.scr_menu, target_colour, LV_PART_MAIN | LV_STATE_DEFAULT);
		lv_obj_set_style_bg_color(objects.scr_digital_clock, target_colour, LV_PART_MAIN | LV_STATE_DEFAULT);
		lv_obj_invalidate(lv_screen_active());
	}
}

/**
 * @brief Utility function for changing the text and accent colours of the UI
 * 
 * @param colour colours_t colour index
 */
void update_text_colour(colours_t colour) {
	lv_color_t current_text_colour = lv_obj_get_style_text_color(objects.label_time_hr_digital_clock, LV_PART_MAIN);
	lv_color_t target_colour = get_color_from_index(colour);
	if(lv_color_to_u32(target_colour) != lv_color_to_u32(current_text_colour)) {
		LOG_DBG("Setting new text colour");
		lv_style_set_text_color(temp_style_spinboxes_menu, target_colour);
		lv_style_set_text_color(temp_style_spinboxes_menu_FOCUSKEY, target_colour);
		lv_style_set_text_color(temp_style_spinboxes_menu_CURSOR, target_colour);
		lv_style_set_outline_color(temp_style_spinboxes_menu, target_colour);
		lv_style_set_outline_color(temp_style_spinboxes_menu_FOCUSKEY, target_colour);
		lv_style_set_text_color(temp_style_spinboxes_digital_clock, target_colour);
		lv_style_set_text_color(temp_style_spinboxes_digital_clock_FOCUSKEY, target_colour);
		lv_style_set_text_color(temp_style_spinboxes_digital_clock_CURSOR, target_colour);
		lv_style_set_outline_color(temp_style_spinboxes_digital_clock, target_colour);
		lv_style_set_outline_color(temp_style_spinboxes_digital_clock_FOCUSKEY, target_colour);
		lv_style_set_line_color(temp_style_scale_analog_clock, target_colour);
		lv_style_set_line_color(temp_style_scale_analog_clock_INDICATOR, target_colour);
		lv_style_set_line_color(temp_style_scale_analog_clock_ITEMS, target_colour);
		lv_style_set_text_color(temp_style_rollers_menu, target_colour);
		lv_style_set_text_color(temp_style_rollers_menu_FOCUSKEY, target_colour);
		lv_style_set_text_color(temp_style_rollers_menu_SELECTED, target_colour);
		lv_style_set_outline_color(temp_style_rollers_menu, target_colour);
		lv_style_set_outline_color(temp_style_rollers_menu_FOCUSKEY, target_colour);
		lv_style_set_text_color(temp_style_labels_menu, target_colour);
		lv_style_set_text_color(temp_style_labels_digital_clock, target_colour);
		lv_style_set_text_color(temp_style_labels_analog_clock, target_colour);
		lv_style_set_text_color(temp_style_buttons_menu, target_colour);
		lv_style_set_text_color(temp_style_buttons_menu_FOCUSKEY, target_colour);
		lv_style_set_outline_color(temp_style_buttons_menu, target_colour);
		lv_style_set_outline_color(temp_style_buttons_menu_FOCUSKEY, target_colour);
		lv_style_set_text_color(temp_style_buttons_digital_clock_set_time, target_colour);
		lv_style_set_text_color(temp_style_buttons_digital_clock_set_time_FOCUSKEY, target_colour);
		lv_style_set_outline_color(temp_style_buttons_digital_clock_set_time, target_colour);
		lv_style_set_outline_color(temp_style_buttons_digital_clock_set_time_FOCUSKEY, target_colour);
		lv_style_set_line_color(temp_style_line_hr_analog_clock, target_colour);
		lv_style_set_line_color(temp_style_line_min_analog_clock, target_colour);
		lv_led_set_color(objects.led_dot_analog_clock, target_colour);
		lv_obj_invalidate(lv_screen_active());
	}
}

/**
 * @brief Read the most recent data written to flash
 * 
 * @param out Pointer to user_settings_t struct which the settings get loaded into
 * 
 * @retval True if succesful, false if failed
 */
bool settings_flash_load(user_settings_t *out) {
	size_t off = 0;
	bool found = false;

	while (off + sizeof(struct settings_record) <= fa->fa_size) {
		struct settings_record rec;

		flash_area_read(fa, off, &rec, sizeof(rec));

		if(rec.magic != SETTINGS_MAGIC) {
			break;
		}

		if(rec.length == sizeof(user_settings_t)) {
			uint32_t crc = crc32_ieee((uint8_t *) &rec.settings, sizeof(user_settings_t));
			if(crc == rec.crc) {
				*out = rec.settings;
				found = true;
			}
		}

		off += ROUND_UP(sizeof(rec), 4);
	}
	return found;
}

/**
 * @brief Utility function for finding the memory offset of the most recent flash write
 * 
 * @retval Flash memory offset
 */
static size_t flash_find_tail(void) {
	size_t off = 0;

	while (off + sizeof(struct settings_record) <= fa->fa_size) {
		struct settings_record rec;

		flash_area_read(fa, off, &rec, sizeof(rec));

		if(rec.magic != SETTINGS_MAGIC || rec.length != sizeof(user_settings_t)) {
			break;
		}

		uint32_t crc = crc32_ieee((uint8_t *) &rec.settings, sizeof(user_settings_t));

		if(crc != rec.crc) {
			break;
		}

		off += ROUND_UP(sizeof(rec), 4);
	}

	return off;
}

/**
 * @brief Initilize the internal STM32 flash
 */
void settings_flash_init(void) {
	flash_area_open(FIXED_PARTITION_ID(user_storage), &fa);
	write_offset = flash_find_tail();
}

/**
 * @brief Write settings struct to internal STM32 flash
 * 
 * @param in Pointer to user_settings_t struct with settings to be saved to flash
 * 
 * @retval -1 if writing to flash failed, else 0
 */
int settings_flash_save(const user_settings_t *in) {
	int ret;

	struct settings_record rec = {
		.magic = SETTINGS_MAGIC,
		.version = 1,
		.length = sizeof(user_settings_t),
		.crc = crc32_ieee((uint8_t *) in, sizeof(user_settings_t)),
		.settings = *in
	};

	size_t rec_size = ROUND_UP(sizeof(rec), 4);

	if (write_offset + rec_size > fa->fa_size) {
		flash_area_erase(fa, 0, fa->fa_size);
		write_offset = 0;
	}

	ret = flash_area_write(fa, write_offset, &rec, sizeof(rec));
	if(ret) return -1;
	write_offset += rec_size;

	return 0;
}

/* Required implementations for EEZ UI */
/**
 * @brief EEZ Studio utility function for UI variables
 * 
 * @retval Value of UI variable time_hr
 */
const char *get_var_time_hr_global() {
    return time_hr_global;
}

/**
 * @brief EEZ Studio utility function for UI variables
 * 
 * @param value Value to write to UI variable time_hr
 */
void set_var_time_hr_global(const char *value) {
    strncpy(time_hr_global, value, sizeof(time_hr_global) / sizeof(char));
    time_hr_global[sizeof(time_hr_global) / sizeof(char) - 1] = 0;
}

/**
 * @brief EEZ Studio utility function for UI variables
 * 
 * @retval Value of UI variable time_min
 */
const char *get_var_time_min_global() {
    return time_min_global;
}

/**
 * @brief EEZ Studio utility function for UI variables
 * 
 * @param value Value to write to UI variable time_min
 */
void set_var_time_min_global(const char *value) {
    strncpy(time_min_global, value, sizeof(time_min_global) / sizeof(char));
    time_min_global[sizeof(time_min_global) / sizeof(char) - 1] = 0;
}

/**
 * @brief LVGL Action CB when flush completes
 * 
 * @param e lv_event_t pointer with info of LVGL event which triggered callback
 */
void action_flush_finished(lv_event_t *e) {
	uint8_t code = (uint32_t) lv_event_get_user_data(e);
	if(code == 0) flush_cb_cntr++;

	if(flush_cb_cntr > 10) {
		/* Turn on display backlight */
		pwm_set_dt(&LCD_kathode_pwm, PWM_PERIOD, PWM_PERIOD * ((float) user_settings.brightness / (float) 100));
		lv_display_remove_event_cb_with_user_data(lv_display_get_default(), action_flush_finished, (void *)0);
	}
}
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
int main(void)
{
	int ret;
	/* devicetree setup*/
	ret = setup_dt();	
	if (ret < 0) {
		LOG_ERR("setup_dt failed. Err: %d\n", ret);
    //     return -1;
    }
	LOG_INF("Devicetree setup complete");

	/* Flash setup */
	settings_flash_init();
	
	/* Read settings from flash */
	if(settings_flash_load(&user_settings)) {
		LOG_INF("Loaded settings from flash");
		LOG_INF("%d, %d, %d, %d, %d, %d", 
				user_settings.brightness, 
				user_settings.clock_type, 
				user_settings.background_colour, 
				user_settings.text_colour, 
				user_settings.time_hr, 
				user_settings.time_min);
	}
	else LOG_WRN("Failed to retreive settings from flash");

	/* LVGL and EEZ UI setup */
	ret = setup_lvgl();
	if (ret < 0) {
		LOG_ERR("setup_lvgl failed. Err: %d\n", ret);
    //     return -1;
    }
	LOG_INF("LVGL setup complete");

	/* Apply some settings */
	next_screen = user_settings.clock_type;

	/* Initial time */
	display_time();

	/* MUST BE SET TO TRUE /AFTER/ LOADING USER SETTINGS AND ASSIGNING TO WIDGETS */
	setup_done = true;

	/* MAIN LOOP */
	LOG_INF("Running");
	while (1) {

		check_screen_switching();

		lv_task_handler(); // Handle LVGL-related tasks
		ui_tick(); // Handle EEZ UI-related tasks
		
		/* Update the time on widgets which are relevant for the current screen */
		if((current_screen == SCREEN_DIGITAL_CLOCK) || (current_screen == SCREEN_ANALOG_CLOCK)) {
			display_time();
		}

		/* Time for other Zephyr-related threads */
		k_sleep(K_MSEC(FRAME_TIME_TARGET));
	}

	return -1;
}

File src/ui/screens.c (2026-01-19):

#include <string.h>

#include "screens.h"
#include "images.h"
#include "fonts.h"
#include "actions.h"
#include "vars.h"
#include "styles.h"
#include "ui.h"

#include "../settings.h"

#include <string.h>

groups_t groups;
static bool groups_created = false;

objects_t objects;
lv_obj_t *tick_value_change_obj;
uint32_t active_theme_index = 0;

static void event_handler_cb_scr_digital_clock_scr_digital_clock(lv_event_t *e) {
    lv_event_code_t event = lv_event_get_code(e);
    if (event == LV_EVENT_SCREEN_LOAD_START) {
        // group: group_menu
        lv_group_remove_all_objs(groups.group_menu);
        // group: group_digital_clock
        lv_group_remove_all_objs(groups.group_digital_clock);
        lv_group_add_obj(groups.group_digital_clock, objects.label_time_hr_digital_clock);
        lv_group_add_obj(groups.group_digital_clock, objects.label_time_min_digital_clock);
        // group: group_digital_clock_set_time
        lv_group_remove_all_objs(groups.group_digital_clock_set_time);
        lv_group_add_obj(groups.group_digital_clock_set_time, objects.spinbox_hr_digital_clock_set_time);
        lv_group_add_obj(groups.group_digital_clock_set_time, objects.spinbox_min_digital_clock_set_time);
        lv_group_add_obj(groups.group_digital_clock_set_time, objects.button_digital_clock_set_time_cancel);
        lv_group_add_obj(groups.group_digital_clock_set_time, objects.button_digital_clock_set_time_menu);
        lv_group_add_obj(groups.group_digital_clock_set_time, objects.button_digital_clock_set_time_ok);
        // group: group_analog_clock
        lv_group_remove_all_objs(groups.group_analog_clock);
        lv_group_add_obj(groups.group_analog_clock, objects.scale_analog_clock);
        lv_group_add_obj(groups.group_analog_clock, objects.led_dot_analog_clock);
        // group: grou_analog_clock_set_time
        lv_group_remove_all_objs(groups.grou_analog_clock_set_time);
    }
}

static void event_handler_cb_scr_menu_scr_menu(lv_event_t *e) {
    lv_event_code_t event = lv_event_get_code(e);
    if (event == LV_EVENT_SCREEN_LOAD_START) {
        // group: group_menu
        lv_group_remove_all_objs(groups.group_menu);
        lv_group_add_obj(groups.group_menu, objects.spinbox_menu_brightness);
        lv_group_add_obj(groups.group_menu, objects.roller_menu_clock_type);
        lv_group_add_obj(groups.group_menu, objects.roller_menu_background_colour);
        lv_group_add_obj(groups.group_menu, objects.roller_menu_text_colour);
        lv_group_add_obj(groups.group_menu, objects.button_menu_cancel);
        lv_group_add_obj(groups.group_menu, objects.button_menu_save);
        // group: group_digital_clock
        lv_group_remove_all_objs(groups.group_digital_clock);
        // group: group_digital_clock_set_time
        lv_group_remove_all_objs(groups.group_digital_clock_set_time);
        // group: group_analog_clock
        lv_group_remove_all_objs(groups.group_analog_clock);
        // group: grou_analog_clock_set_time
        lv_group_remove_all_objs(groups.grou_analog_clock_set_time);
    }
}

void create_screen_scr_digital_clock() {
    lv_obj_t *obj = lv_obj_create(0);
    objects.scr_digital_clock = obj;
    lv_obj_set_pos(obj, 0, 0);
    lv_obj_set_size(obj, 240, 240);
    lv_obj_add_event_cb(obj, event_handler_cb_scr_digital_clock_scr_digital_clock, LV_EVENT_ALL, 0);
    lv_obj_clear_flag(obj, LV_OBJ_FLAG_PRESS_LOCK|LV_OBJ_FLAG_CLICK_FOCUSABLE|LV_OBJ_FLAG_GESTURE_BUBBLE|LV_OBJ_FLAG_SNAPPABLE|LV_OBJ_FLAG_SCROLLABLE|LV_OBJ_FLAG_SCROLL_ELASTIC|LV_OBJ_FLAG_SCROLL_MOMENTUM|LV_OBJ_FLAG_SCROLL_CHAIN_HOR|LV_OBJ_FLAG_SCROLL_CHAIN_VER);
    lv_obj_set_scrollbar_mode(obj, LV_SCROLLBAR_MODE_OFF);
    lv_obj_set_scroll_dir(obj, LV_DIR_NONE);
    lv_obj_set_scroll_snap_x(obj, LV_SCROLL_SNAP_NONE);
    lv_obj_set_scroll_snap_y(obj, LV_SCROLL_SNAP_NONE);
    lv_obj_set_style_bg_color(obj, get_color_from_index(user_settings.background_colour), LV_PART_MAIN | LV_STATE_DEFAULT);
    {
        lv_obj_t *parent_obj = obj;
        {
            // cont_digital_clock_set_time
            lv_obj_t *obj = lv_obj_create(parent_obj);
            objects.cont_digital_clock_set_time = obj;
            lv_obj_set_pos(obj, 0, 0);
            lv_obj_set_size(obj, 240, 240);
            lv_obj_set_style_pad_left(obj, 0, LV_PART_MAIN | LV_STATE_DEFAULT);
            lv_obj_set_style_pad_top(obj, 0, LV_PART_MAIN | LV_STATE_DEFAULT);
            lv_obj_set_style_pad_right(obj, 0, LV_PART_MAIN | LV_STATE_DEFAULT);
            lv_obj_set_style_pad_bottom(obj, 0, LV_PART_MAIN | LV_STATE_DEFAULT);
            lv_obj_set_style_bg_opa(obj, 0, LV_PART_MAIN | LV_STATE_DEFAULT);
            lv_obj_set_style_border_width(obj, 0, LV_PART_MAIN | LV_STATE_DEFAULT);
            lv_obj_set_style_radius(obj, 0, LV_PART_MAIN | LV_STATE_DEFAULT);
            lv_obj_clear_flag(obj, LV_OBJ_FLAG_CLICKABLE|LV_OBJ_FLAG_CLICK_FOCUSABLE|LV_OBJ_FLAG_GESTURE_BUBBLE|LV_OBJ_FLAG_PRESS_LOCK|LV_OBJ_FLAG_SCROLLABLE|LV_OBJ_FLAG_SCROLL_CHAIN_HOR|LV_OBJ_FLAG_SCROLL_CHAIN_VER|LV_OBJ_FLAG_SCROLL_ELASTIC|LV_OBJ_FLAG_SCROLL_MOMENTUM|LV_OBJ_FLAG_SCROLL_WITH_ARROW|LV_OBJ_FLAG_SNAPPABLE);
            lv_obj_set_scrollbar_mode(obj, LV_SCROLLBAR_MODE_OFF);
            lv_obj_set_scroll_dir(obj, LV_DIR_NONE);
            lv_obj_set_scroll_snap_x(obj, LV_SCROLL_SNAP_NONE);
            lv_obj_set_scroll_snap_y(obj, LV_SCROLL_SNAP_NONE);
            lv_obj_set_style_layout(obj, LV_LAYOUT_FLEX, LV_PART_MAIN | LV_STATE_FOCUSED);
            lv_obj_set_style_flex_flow(obj, LV_FLEX_FLOW_ROW, LV_PART_MAIN | LV_STATE_FOCUSED);
            lv_obj_set_style_flex_main_place(obj, LV_FLEX_ALIGN_CENTER, LV_PART_MAIN | LV_STATE_FOCUSED);
            lv_obj_set_style_flex_cross_place(obj, LV_FLEX_ALIGN_START, LV_PART_MAIN | LV_STATE_FOCUSED);
            lv_obj_set_style_flex_track_place(obj, LV_FLEX_ALIGN_CENTER, LV_PART_MAIN | LV_STATE_FOCUSED);
            lv_obj_set_style_layout(obj, LV_LAYOUT_FLEX, LV_PART_MAIN | LV_STATE_DEFAULT);
            lv_obj_set_style_flex_flow(obj, LV_FLEX_FLOW_ROW, LV_PART_MAIN | LV_STATE_DEFAULT);
            lv_obj_set_style_flex_main_place(obj, LV_FLEX_ALIGN_CENTER, LV_PART_MAIN | LV_STATE_DEFAULT);
            lv_obj_set_style_flex_cross_place(obj, LV_FLEX_ALIGN_CENTER, LV_PART_MAIN | LV_STATE_DEFAULT);
            lv_obj_set_style_flex_track_place(obj, LV_FLEX_ALIGN_CENTER, LV_PART_MAIN | LV_STATE_DEFAULT);
            {
                lv_obj_t *parent_obj = obj;
                {
                    // spinbox_hr_digital_clock_set_time
                    lv_obj_t *obj = lv_spinbox_create(parent_obj);
                    objects.spinbox_hr_digital_clock_set_time = obj;
                    lv_obj_set_pos(obj, -10445, -6613);
                    lv_obj_set_size(obj, LV_PCT(38), LV_PCT(30));
                    lv_spinbox_set_digit_format(obj, 2, 0);
                    lv_spinbox_set_range(obj, 0, 23);
                    lv_spinbox_set_rollover(obj, true);
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

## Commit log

2025-12-16 Added some more files for custom board definition
2025-12-22 Removed the remnants of the in-project board directory. It's now located in the main Zephyr tree under /boards/yopocho/mantelclock
2025-12-23 Finally fixed the PWM device, previously used the wrong device handle but it's fixed now :')
    Back to having the boards directory in-project, as opposed to what Zephyr wants (which is annoying to track with git). Build from the project directory with: west build -p always -b mantelclock -- -DBOARD_ROOT=.
    [main.c]
2025-12-24 Display driver is functional, but nothing on the screen. Issue might be hardware at this point...
    [main.c]
2025-12-28 Starting to converge on a correct devicetree and config! Also enabled logging and stuff because I connected an ST-Link via an STM32F4DISCO
    [main.c]
2025-12-29 Enabled logging on SWO-pin and switched the printk's to LOG_ calls.
2026-01-02 PARTIALLY WORKING DISPLAY! The screen now shows random pixels and the SWO works! Zephyr crashes when doing ANYTHING with a display buffer or anything, so gotta fix that. Just using the hello world ex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
    [main.c]
2026-01-03 Trying to get the regulator-fixed working... Right now the clock is just straight up doing nothing :') Starting to despise Zephyr??????????
    [main.c]
2026-01-03 Regulator initializes before SPI and display and LVGL now, the system does run. For some reason the display does not get initialized tho, will investigate
2026-01-04 Progress! Using screens to display different status of the UI now. The UI gets activated when on scr_digital_clock but the callback for user interaction is broken, FIXME
    [main.c]
2026-01-05 Headache. The callbacks don't work for anything and it's properly preventing me from making progress.
    [main.c]
2026-01-06 Using labels for scr_digital_clock now as that just makes more sense. Switching screens to scr_digital_clock_set_time also works now! CB from adjusting the spinboxes not implemented/working yet
2026-01-06 Many changes to scr_digital_clock_set_time. Starting to rethink the idea of adding an analog clock-face as that will be 1000x harder than this digital clock so far. Should've just used u8g2...... Cur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
2026-01-07 Trying LVGL a different way, using EEZ studio. Removed all the (what I currently presume) is unnecessary as I begin porting.
2026-01-07 THIS IS ALREADY WORKING! First screen works, now to make the indev work and switch to scr_digital_clock_set_time
2026-01-07 Added display switching! Indev still isn't working though :')
2026-01-07 Indev is now properly for switching screens and such
2026-01-07 Started shaping the menu screen, but progress is haulted due to RAM issues when switching screens. Start looking into optimizations (e.g. LVGL minimal config, kconfig memory allocation)
    [main.c, screens.c]
2026-01-09 Small optimizations, removed the 2 _clock_set_time screens and just hiding/unhiding the spinboxes and buttons. Indev currently does not work yet when focussing the un-hidden widgets, even after setti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
    [main.c, screens.c]
2026-01-10 Added monospaced Courier New fonts to help with layout. Started work on analog clock face but not much progress yet. Menu screens is going well, but again the indev is not navigating between the widg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
    [main.c, screens.c]
2026-01-12 Partly working read-out and application of user settings on boot. Text colour is broken right now, see FIXME main.c:878
    [main.c]
2026-01-14 Moved applying the user settings to the screen switching function, as they were the cause of crashes on start-up. Added a tiny bit of analog clock functionality, but not ready at all yet.
    [main.c]
2026-01-18 Added comments, briefs and removed/replaced reduntent code
    [main.c]
2026-01-18 Upped the MCU core freq to 168MHz while keeping SPI1 at 21MHz as 42MHz is too unstable for the current hardware
2026-01-18 Fixed the bouncing spinboxes, increased VDB to 20% among other small optimalizations
    [main.c, screens.c]
2026-01-19 Some more work on changing the text colours. Currently (almost) everything gets applied, but the program crashes when applying text colour on start-up. Also decreased the physical size of the colour-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
    [main.c, screens.c]
2026-01-19 All colour settings now get applied to all widget parts! Still working on the bug with the crash on start-up when applying text colour changes
    [main.c]
2026-01-19 Schematics, gerbers and JLCPCB BOM and CPL files
    [Kerst_2025_PCB-BOM.csv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]
2026-01-19 Included ui/styles.h to fix some compile warnings, lightened the pink a bit on Eva's request :)
    [main.c]
2026-01-26 Implemented feedback from Geert regarding blocking the user from selecting the same colour for both the bg and text at the same time. Now if one option has a colour selected and the user tries to set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
    [main.c]
2026-01-26 Moved some project configuration options from the board defaults to project specific file as some aren't inherently necessary for the board itself
2026-01-26 Some type casting to mitigate conversion warnings/errors
    [main.c]
2026-01-26 Decreased pause between frames from 50ms to 10ms, effectively increasing fps from ~20 to ~100 :)
2026-02-02 Added some additional logging which fixed the looping colour bug :') Probably has something to do with task timing, input resampling and wait-time for LVGL atrributes to update.
    [main.c]
2026-02-02 Replaced the previous "fix" for the endless looping of colour with an actual fix :')
    [main.c]
2026-02-02 Addition design file + media
    [Mantel_Clock_Stand.stl]
